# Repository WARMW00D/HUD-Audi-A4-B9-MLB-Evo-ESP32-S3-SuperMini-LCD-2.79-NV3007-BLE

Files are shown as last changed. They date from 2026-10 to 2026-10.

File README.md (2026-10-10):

# HUD for Audi A4 B9 (MLB-Evo) — ESP32-S3 Super Mini / NV3007 2.79″ / BLE

[Русская версия](README_ru.md) · [Android companion app](https://github.com/WARMW00D/HUD-Audi-A4-B9-MLB-Evo-Android-App)

A DIY head-up display showing vehicle data from Audi I-CAN: speed, gear, ACC, speed limiter, driver assistance, traffic signs, doors and navigation. This is the compact **428 × 142 NV3007** adaptation of the [Waveshare 3.49″ project](https://github.com/WARMW00D/HUD-Audi-A4-B9-MLB-Evo-Waveshare-ESP32-S3-Touch-LCD-3.49), with Android settings and firmware updates over BLE.

**Verified vehicle configuration:** operation was checked on an **Audi A4 B9 facelift (restyling) with MIB3 High infotainment**.

**Firmware: v29.1.9. Android app: 1.4.1.** This repository contains firmware source and wiring diagrams. Android source lives in its own repository. Prebuilt v29.1.9 app firmware and Android 1.4.1 APKs are available in Releases below.

## Tank capacity, acceleration bar and overspeed tolerance

Source versions: **HUD firmware v29.1.9 / Android app 1.4.1 (versionCode 5)**.

- **Tank capacity:** enter a whole number from **1 to 200 litres**; default **54 L**. The capacity is always entered in litres, even with US gallons selected, and updates the HUD fuel-to-add calculation.
- **Acceleration bar:** turn it on or off from the app. When enabled, the existing bar uses valid acceleration/speed data; it remains empty while stationary or without valid data.
- **Overspeed tolerance:** set **0–100 km/h**, default **20 km/h**, always entered in km/h even with mph selected. The red speed outline fades in from 75% of tolerance and is fully red at 100%; zero makes any positive overspeed fully red.
- All three settings are confirmed by BLE readback and saved in HUD NVS. Existing settings, phone owner and gateway bonds are retained. A BOOT phone-binding reset also retains these settings.

These controls need **app 1.4.1 + firmware v29.1.9**. App 1.4.1 still supports older firmware: missing controls are disabled. Maintainer-supplied APK 1.4.1 and v29.1.9 app-BIN are published in Releases; integrity was verified. If v29.0 and its OTA partition table are already installed, v29.1 uses the same layout; earlier firmware needs the initial USB/partition upgrade described below.

## HUD on hardware

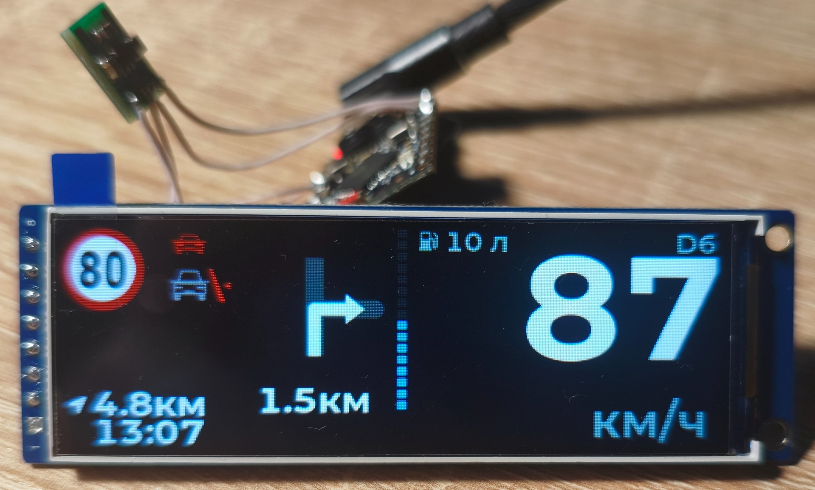
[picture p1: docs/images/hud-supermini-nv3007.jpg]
ESP32-S3 SuperMini HUD on the NV3007 2.79-inch display


Photo supplied by WARMW00D: speed, gear, speed-limit sign, navigation and fuel information on the NV3007 display.

## Download firmware BIN

[v29.1 release](https://github.com/WARMW00D/HUD-Audi-A4-B9-MLB-Evo-ESP32-S3-SuperMini-LCD-2.79-NV3007-BLE/releases/tag/v29.1.9) · [App-BIN](https://github.com/WARMW00D/HUD-Audi-A4-B9-MLB-Evo-ESP32-S3-SuperMini-LCD-2.79-NV3007-BLE/releases/download/v29.1.9/HUD-SuperMini-v29.1.9-app.bin) · [SHA-256](https://github.com/WARMW00D/HUD-Audi-A4-B9-MLB-Evo-ESP32-S3-SuperMini-LCD-2.79-NV3007-BLE/releases/download/v29.1.9/SHA256SUMS-v29.1.9.txt).

Maintainer-supplied image, **1,149,616 bytes**. ESP32-S3 header, image checksum and SHA-256 were verified. **OTA application only**: no bootloader or partition table. Initial installation requires USB with the project `partitions.csv`; this app-BIN cannot migrate partitions. The v29.0 two-slot OTA layout is compatible. Real-device OTA transfer has not been verified here.

## Download Android APK

[Version 1.3](https://github.com/WARMW00D/HUD-Audi-A4-B9-MLB-Evo-Android-App/releases/tag/v1.4.1) — **Pre-release**, pending real-device OTA validation.

- [Release APK](https://github.com/WARMW00D/HUD-Audi-A4-B9-MLB-Evo-Android-App/releases/download/v1.4.1/HUD-Control-1.4.1-release.apk) — normal installation, 58.4 KB.
- [Debug APK](https://github.com/WARMW00D/HUD-Audi-A4-B9-MLB-Evo-Android-App/releases/download/v1.4.1/HUD-Control-1.4.1-debug.apk) — 66.5 KB; `testOnly=true`: `adb install -r -t HUD-Control-1.4.1-debug.apk`.
- [SHA-256](https://github.com/WARMW00D/HUD-Audi-A4-B9-MLB-Evo-Android-App/releases/download/v1.4.1/SHA256SUMS-v29.1.9.txt).

WARMW00D supplied these builds: version 1.3 (versionCode 4). APK v2 signatures and content digests were verified. Each flavor retains its previous signing key: release updates release and debug updates debug. Switching flavors requires uninstalling the app and loses its local settings.

## What the HUD shows

| Element | Behaviour |
|---|---|
| Speed and gearbox | Cluster digital speed; P/R/N/D/S/M/E/Offroad and gear number when available |
| ACC and limiter | Set speed, ACC target and traffic jam assist; LIM replaces the ACC set-speed icon |
| Lane / Side Assist | Lane detection, steering and warnings; red lines for blind-spot indications |
| Traffic signs | Main sign: valid VZE → explicit PSD → PSD legal limit; additional signs cycle |
| Overspeed | Red outline around speed digits, based on the displayed main limit |
| Navigation | Main maneuver, next maneuver, distance, progress bar, destination distance and time |
| Doors / pre sense | Open vehicle parts replace navigation; pre sense has higher priority |
| Turn signals | Green arrows; hazard lights use red |
| Fuel | Amount to fill and consumption strip when the required data is available |
| Acceleration | Optional bar, selected by build-time configuration |
| Brightness | Vehicle light sensor × dimmer wheel; night range **2–40**, sunlight **200–255** |
| Settings | PSD, VZE, HUD language, distance/speed units and fuel-volume units; stored in NVS |

Stale fields are hidden. A signal must exist on your car’s bus to be displayed. This board has no Waveshare touch controller, audio codec or SD logging; settings use the phone. The phone app language is independent of the HUD language.

## Architecture

The HUD decodes raw frames locally using `can_decode.c`. Select the source in `supermini_hud/hud_config.h`:

| Mode | Source |
|---|---|
| `HUD_SRC_AUTO` — default | Own CAN while frames arrive; after 1 s of silence, use the BLE gateway |
| `HUD_SRC_TWAI` | Direct CAN through TJA1051T/3, TWAI `LISTEN_ONLY` |
| `HUD_SRC_BLE` | Raw CAN frames from a compatible gateway / sniffer |
| `HUD_SRC_FAKE` | Built-in generator for bench testing |

The [CAN sniffer / BLE gateway](https://github.com/WARMW00D/esp32-CAN-sniffer-logger-screener) uses the ACL protocol (firmware 2.6.0+). The HUD sends its ACL after every gateway connection. Phone settings and OTA are separate GATT services; NimBLE acts as both gateway client and phone server. First-time gateway pairing waits if the phone is connected.

LVGL renders a compact 518 × 172 canvas, uniformly scales it to 428 × 142, and sends changed strips over SPI. Display code uses PSRAM; no LVGL calls should be added from BLE callbacks.

[CAN signals and gateway protocol](docs/CAN.md) · [BLE settings, Russian](supermini_hud/BLE_SETTINGS_ru.md)

## Hardware and wiring

- **ESP32-S3 Super Mini:** the project targets the supplied 4 MB Flash / 2 MB QSPI PSRAM board. Check your board variant.
- **NV3007 2.79″:** 428 × 142, SPI, with a logic backlight-control input.
- **TJA1051T/3:** VIO-equipped CAN module with a 3.3 V logic interface.
- ACC 12 V → external DC-DC 12→5 V. The 5 V rail supplies the ESP32 board and the **input** of a separate DC-DC 5→3.3 V for the display.

**Display VDD comes from the separate converter’s 3.3 V output (`3V3_D`). Do not connect that output to the board’s 3V3 pin (`3V3_P`).** All grounds are common. CAN-module VCC comes from the board’s 5V pin; VIO and S come from the board’s 3V3 pin. SN65HVD230 is not used.

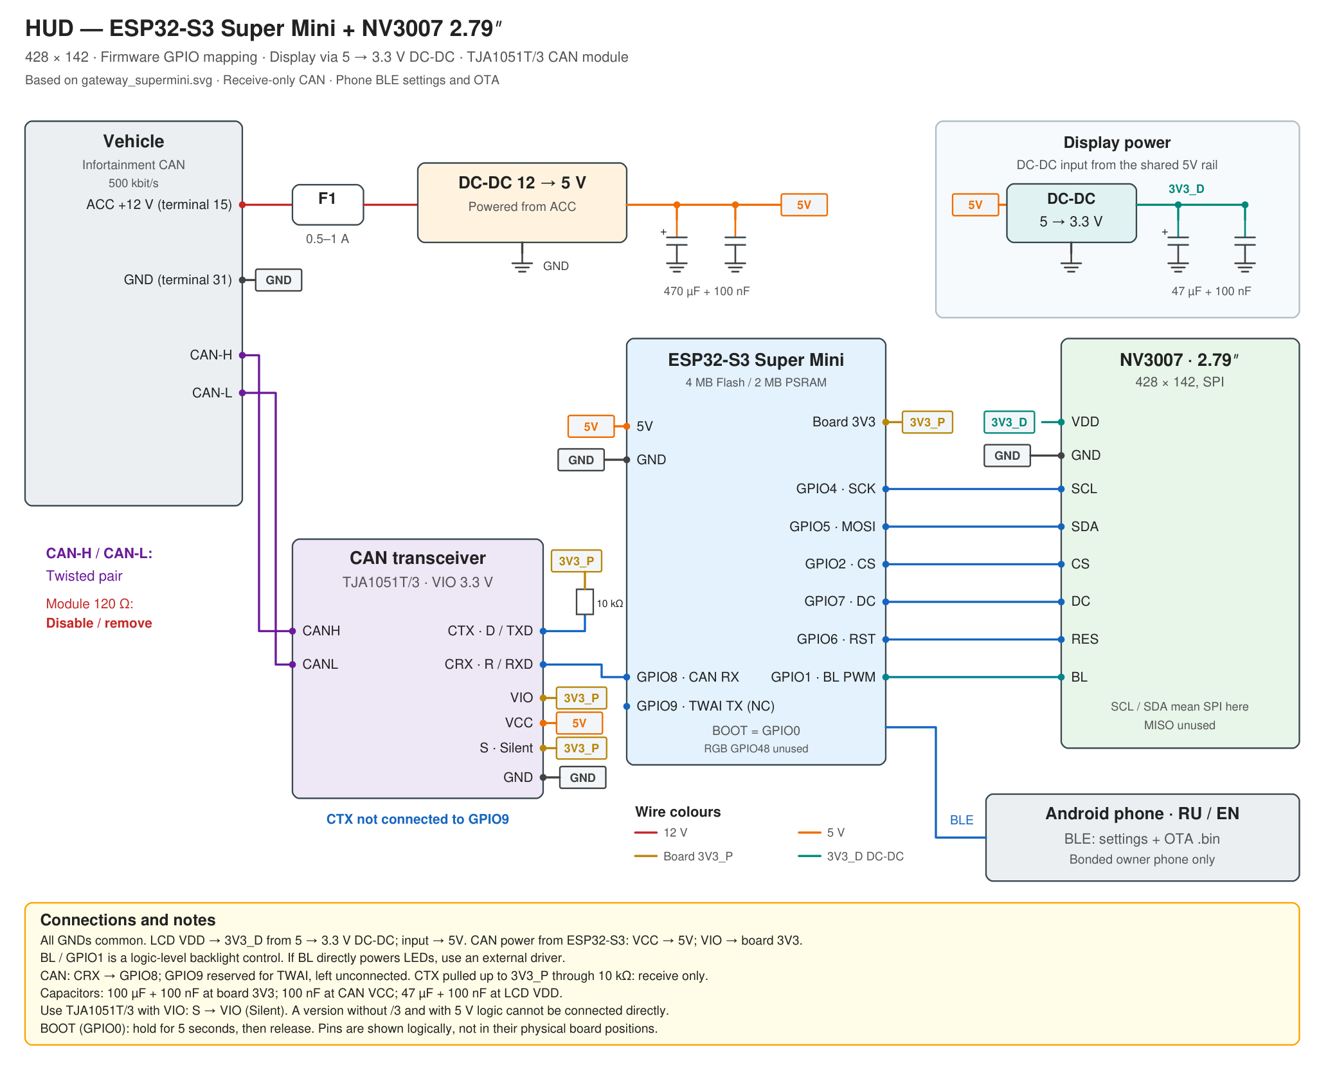
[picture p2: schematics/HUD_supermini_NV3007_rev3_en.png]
HUD wiring, revision 3


[Editable SVG](schematics/HUD_supermini_NV3007_rev3_en.svg) · [PDF](schematics/HUD_supermini_NV3007_rev3_en.pdf)

| ESP32-S3 | Connection |
|---|---|
| GPIO4 | LCD SCL / SPI SCK |
| GPIO5 | LCD SDA / SPI MOSI |
| GPIO2 | LCD CS |
| GPIO7 | LCD DC |
| GPIO6 | LCD RES |
| GPIO1 | LCD BL / PWM |
| GPIO8 | CAN CRX / RXD |
| GPIO9 | TWAI TX reservation — leave physically unconnected |
| GPIO0 | On-board BOOT button |

CAN CTX/TXD → 10 kΩ → board 3V3; S → VIO for silent mode. CAN-H / CAN-L are a twisted pair. Disable the module’s 120 Ω termination when connecting to an already terminated vehicle bus. Receive-only protection combines TWAI `LISTEN_ONLY`, disconnected GPIO9 and hardware silent mode. SCL/SDA labels on this display refer to SPI, not I²C; MISO is unused. If BL directly powers LEDs instead of being a logic input, use a suitable external driver.

The drawing is a wiring diagram, not a PCB layout or a complete automotive power-protection design. USB power isolation is not drawn; account for it when flashing while external 5 V is connected.

## 3D-printed enclosure

The [`case/`](case/) folder contains an ASA enclosure for the NV3007 2.79″ display: a top shell with a visor and a bottom plate secured with screws from below.

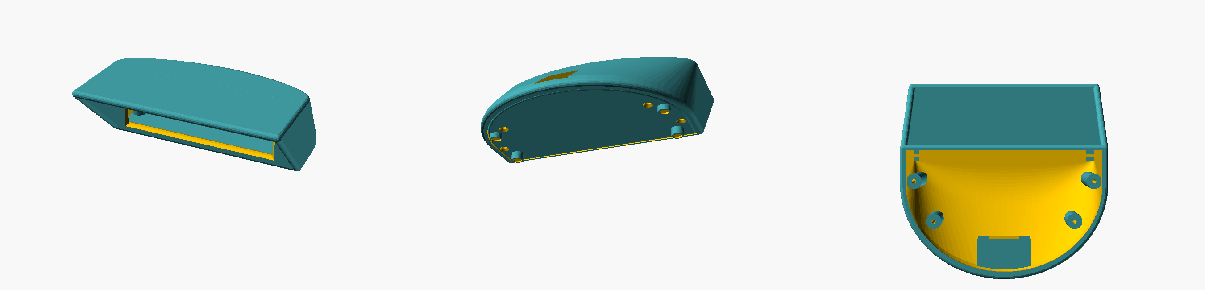
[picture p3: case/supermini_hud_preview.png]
SuperMini HUD enclosure preview


| Part | STL for printing | STEP for CAD |
|---|---|---|
| Top shell with visor | [STL](case/supermini_hud_shell.stl) | [STEP](case/supermini_hud_shell.step) |
| Top shell with long visor, variant 2 | [STL](case/supermini_hud_shell_var2.stl) | [STEP](case/supermini_hud_shell_var2.step) |
| Bottom plate with feet | [STL](case/supermini_hud_plate.stl) | [STEP](case/supermini_hud_plate.step) |
| Bottom plate without feet | [STL](case/supermini_hud_plate_nofeet.stl) | [STEP](case/supermini_hud_plate_nofeet.step) |
| Separate feet | [STL](case/supermini_hud_feet.stl) | [STEP](case/supermini_hud_feet.step) |

[Parametric OpenSCAD source](case/supermini_hud.scad). Dimensions are in millimetres. Use `PART` to select `assembly`, `shell`, `plate`, `plate_nofeet` or `feet`. The model is designed for **ASA**.

## Build and first USB installation

Open `supermini_hud/supermini_hud.ino` in Arduino IDE. Keep the sketch-folder name `supermini_hud`.

| Item | Project configuration |
|---|---|
| Board | ESP32S3 Dev Module |
| Arduino ESP32 core | 3.3.10, as in the supplied working board configuration |
| CPU | 240 MHz |
| Flash | 4 MB, QIO / 80 MHz, matching your working board |
| PSRAM | QSPI, 2 MB; not OPI |
| USB CDC On Boot | Enabled |
| Partition table | Custom `supermini_hud/partitions.csv` |
| Serial | 115200 |
| Libraries | LVGL 8.4.0; NimBLE-Arduino 2.x / API 2.5.1; Arduino_GFX with `Arduino_NV3007` support |

Put `supermini_hud/config/lv_conf.h` next to the installed `lvgl/` directory. Required: `LV_COLOR_DEPTH 16`, `LV_USE_FONT_COMPRESSED 1`. LVGL 9 is not supported. Both `LV_COLOR_16_SWAP` settings are handled by the display port.

**Upgrading v28.x → v29.0 requires USB flashing of the new partition table. Set Erase All Flash to Disabled.** Confirm the build uses the supplied CSV and writes the table at 0x8000; flashing only the application does not migrate partitions. NVS remains at 0x9000 with size 0x5000, so settings and bonds are intended to survive, subject to device verification.

Two OTA slots are **0x1F0000 / 2,031,616 bytes** each. Check the compiled application size. The first boot should report `[fw] HUD Super Mini v29.1.9 / BLE OTA` and a next-slot capacity of 2031616.

For gateway authentication, copy `secrets.example.h` to `secrets.h` and set its `BLE_PASSKEY` to match the gateway. `secrets.h` is ignored by Git. This is separate from the phone PIN, `HUD_SETTINGS_PIN` in `user_config.h`.

### Optional photoresistor light sensor

The SuperMini can use an optional photoresistor divider on **GPIO10 (ADC1)** when RLS_01 light data is unavailable. Connect the LDR from 3V3 to GPIO10, a 10 kΩ resistor from GPIO10 to GND, and optionally 100 nF from GPIO10 to GND. Calibration is available in the Android app: close the sensor and save the dark point once, then illuminate it with a bright flashlight and save the bright point once.

Photoresistor divider

## Android settings and BLE OTA

1. Download the APK above or build and install the [Android app](https://github.com/WARMW00D/HUD-Audi-A4-B9-MLB-Evo-Android-App).
2. Find `HUD-SuperMini`, connect and complete Android bonding. Phone pairing PIN: see `HUD_SETTINGS_PIN` in [`user_config.h`](supermini_hud/user_config.h).
3. The first authenticated phone becomes the owner. Settings changes are read back and stored in NVS.
4. For OTA, export **`supermini_hud.ino.bin`** from Arduino IDE. Select that application image in the app, then confirm the update.
5. Keep power stable and the phone app open. After verification and boot-slot selection, the HUD reboots; reconnect and check operation.

Do not use bootloader, partition, merged images or flash dumps for OTA. The transfer validates offsets, SHA-256, the ESP32-S3 application header and the ESP-IDF image before selecting the new slot. Only the bonded, authenticated owner may update. A lost final acknowledgment can mean the update has already committed; follow the app’s restart/check message before retrying. Functional rollback of a faulty new program is not guaranteed; USB is the recovery method.

To replace the phone: while the HUD is running, hold **BOOT for 5 s and release**. Only the phone ownership/bonds are reset; HUD settings and gateway keys remain. Remove the old HUD bond on the phone before pairing again. Do not hold BOOT during power-on/reset.

[Full OTA guide](docs/OTA.md) · [Полная инструкция OTA](docs/OTA_ru.md)

## Configuration and diagnostics

`user_config.h` defines LCD GPIO, orientation, column offsets, SPI clock, phone name/PIN and BOOT. `hud_config.h` defines data source, sign selection defaults, units, tank size, brightness and Serial logging. Stored phone settings override initial defaults.

| Setting | Default |
|---|---|
| `HUD_CAN_RX_PIN` / `HUD_CAN_TX_PIN` | 8 / 9, with TX unconnected |
| `HUD_CAN_BITRATE_K` | 500 |
| `HUD_LCD_SPI_HZ` / `HUD_LCD_ROTATION` | 20 MHz / 1 |
| `HUD_BR_DARK_WHEEL_MIN` / `_MAX` | 2 / 40 |
| `HUD_BR_BRIGHT_WHEEL_MIN` / `_MAX` | 200 / 255 |
| `HUD_LANG` / `HUD_UNITS` | RU / km |
| `HUD_TANK_L` | 54 L |

For bench testing, use `HUD_SRC_FAKE` or a compatible BLE log player. Enable `HUD_LOG_CAN` / `HUD_LOG_STAT` to diagnose missing frames; a field disappearing on timeout does not necessarily indicate a rendering problem. Use `tools/can_bitdiff.py` to inspect changing CAN bits.

| Symptom | Check |
|---|---|
| Custom text missing | `LV_USE_FONT_COMPRESSED 1` and LVGL 8 |
| Black screen / allocation error | QSPI PSRAM enabled, GPIO, power, LCD rotation and column offsets |
| No gateway data | Gateway ACL protocol, name, bonding/passkey and source mode |
| OTA service absent | Install v29.0 over USB; reconnect after Service Changed; check slot capacity |
| App reconnect fails after removing Android bond | Reset phone ownership with BOOT, then pair again |

## Validation status

WARMW00D supplied the v29.1.9 ESP32-S3 application BIN and Android v1.4.1 APKs. Firmware image checksum/SHA-256 and APK signatures/content digests were verified. Host tests pass. Builds were not run here; Android lint and real-device OTA transfer testing remain pending.

Host tests cover real SHA-256 through OpenSSL with mocked NimBLE/ESP-IDF: full transfer, commit only after verification, invalid size/header/chip/hash, flash failures, offsets, cancel/disconnect/timeout, owner authorization, duplicate commit and lost final ACK. Display scaling, dirty strips, decoder and settings/NVS also have host tests. Mocks do not establish real BLE interoperability or flash reliability.

Example from `supermini_hud/` (g++ and OpenSSL development headers required):

```sh
g++ -std=c++17 -Wno-deprecated-declarations -Itests/settings_stubs tests/test_ble_ota.cpp -lcrypto -o /tmp/hud_test_ota
/tmp/hud_test_ota
g++ -std=c++17 -Wno-deprecated-declarations -Itests/settings_stubs tests/test_ble_settings.cpp -lcrypto -o /tmp/hud_test_settings
/tmp/hud_test_settings
```

CAN signal verification depends on the vehicle and equipment. The inherited observations and remaining uncertainties are in [CAN reference](docs/CAN.md). Firmware integrity checks are not a digital signature or proof that a third-party ESP32-S3 image is compatible.

## Files

- `case/` — enclosure models (STL/STEP), parametric OpenSCAD source and preview.
- `supermini_hud/` — Arduino sketch, decoder, LVGL interface, SPI port, BLE gateway client, phone settings and OTA server.
- `supermini_hud/config/` — LVGL configuration example.
- `supermini_hud/tests/` — host tests and stubs.
- `supermini_hud/tools/` — image/font generators, previews and CAN utilities.
- `docs/` — OTA and CAN/gateway guides in English and Russian.
- `schematics/` — Russian and English revision 3 SVG, PNG and PDF with the Infortainment CAN label; display DC-DC input is 5 V. Revision 2 remains available.

## Credits and license

- **WARMW00D (Warmwood):** project owner, hardware integration, vehicle logs and testing.
- **Claude (Anthropic):** development assistance acknowledged by the original Waveshare project.
- **OpenAI Codex / ChatGPT:** assistance with the SuperMini/NV3007 adaptation, BLE settings, Android RU/EN app, BLE OTA, host tests, wiring diagrams and documentation. Generated changes still require maintainer review and hardware validation.
- [CAN sniffer/gateway](https://github.com/WARMW00D/esp32-CAN-sniffer-logger-screener), opendbc/openpilot and revag-bap — data transport and signal/protocol references.
- Waveshare — original project context; Arduino_GFX, LVGL and NimBLE-Arduino — display and BLE libraries.
- Montserrat and Roboto Condensed — fonts under SIL OFL 1.1, licenses in `supermini_hud/tools/fonts/`.

Project code and documentation: [MIT](LICENSE), retaining the original Warmwood copyright. Third-party assets retain their own licenses; the original README notes that `tools/icons/acc_set.png` came from an external source. This hobby project is not affiliated with AUDI AG or Volkswagen AG.

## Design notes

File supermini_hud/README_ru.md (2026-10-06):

# HUD Super Mini / NV3007 — вариант v29.0

Исходная версия: приложенный waveshare_hud_v27_1.zip.
Плата: ESP32-S3 Super Mini, 4 MB Flash / 2 MB QSPI PSRAM.
Дисплей: NV3007 2.79", 142×428 в портретной ориентации, 428×142 в альбомной.

## OTA v29.0

BLE OTA через Android HUD Control 1.2. Первую установку выполнить через USB
вместе с новым partitions.csv, без полного стирания. См. **../docs/OTA_ru.md**.

## Изменения

- Удалены тач и экранное меню настроек. Язык, единицы и PSD/VZE меняются
  по BLE и сохраняются в NVS вместе с владельцем; hud_config.h задаёт значения
  по умолчанию. Остальные графические параметры задаются константами.
- Удалены звук, PCM-файлы, кодек ES8311, I²S и расширитель GPIO TCA9554.
  Side Assist сохраняет визуальные предупреждения, звуков нет.
- Удалены SD-драйвер и файловое логирование, задача записи и буфер журнала.
  Убраны подписка BLE на Diagnose_01 0x6B2 и декодер часов, использовавшийся
  только для имён файлов и временных меток SD-журнала. Диагностика в Serial остаётся.
  Navigation_SD в названиях BAP — имя автомобильного сервиса навигации,
  к физической SD-карте HUD оно отношения не имеет и сохранено.
- QSPI-дисплей AXS15231B заменён на обычный SPI NV3007 через Arduino_GFX.
  Плата Waveshare, SensorLib и её драйверы больше не нужны.
- Сохранены CAN-декодирование остальных сигналов, BLE ACL, TWAI LISTEN_ONLY,
  AUTO/BLE/TWAI/FAKE, автояркость, ассистенты, двери, PSD/VZE, маршрут и расход.

## Раскладка на весь экран

Сначала ширина зоны навигации уменьшена **192 → 128** (ровно в 1.5 раза).
Основные стрелки пересозданы с пропорциональным уменьшением **192×116 → 128×77**;
они центрированы по высоте над прежней строкой дистанции.
Малые стрелки: 38×23 → 25×15. Машинка и PreSense центрированы в узкой зоне.
Свободные горизонтальные промежутки между блоками сокращены; поля выравнивания
скорости и передачи укорочены без изменения размера шрифта. Три цифры скорости
помещаются в поле 244 пикселя (табличный шаг цифры около 81.2 пикселя).
Бар дистанции сделан тоньше, сегменты бара ускорения уплотнены под новую ширину.

Итоговая логическая раскладка **518×172** масштабируется на весь **428×142**:
коэффициент по X 0.82625, по Y 0.82558. Разница менее 0.1%, вызвана округлением
до целых пикселей. Дополнительных чёрных полей и обрезки кадра нет.
Используется билинейное масштабирование RGB565, чтобы сгладить мелкий текст.

Один кадр LVGL занимает **178192 байта PSRAM**; выходной блок 428×8 —
**6848 байт внутренней RAM**. Буфер предыдущего изображения для сравнения полос
занимает ещё **121552 байта PSRAM**; отдельного буфера поворота нет.
Остальная память расходуется LVGL, BLE и исходной логикой. Общий расход памяти,
скорость обновления и размер прошивки требуется измерить после сборки на плате.

## Подключение дисплея

Пины выбраны для этой версии, существующую проводку при необходимости изменить
в user_config.h. Номера GPIO не равны порядковым номерам контактов платы.
На модуле подписи SCL/SDA обозначают **SPI SCK/MOSI**, это не I²C.

| Контакт дисплея | Super Mini | Параметр |
|---|---|---|
| GND | GND | общая земля |
| VDD | 3V3_D выхода DC-DC 5 → 3,3 В | согласно приложенному описанию, VDD допускает 3–5 V |
| SCL | GPIO4 | HUD_LCD_SCK |
| SDA | GPIO5 | HUD_LCD_MOSI |
| RES | GPIO6 | HUD_LCD_RST |
| DC | GPIO7 | HUD_LCD_DC |
| CS | GPIO2 | HUD_LCD_CS |
| BL | управление от GPIO1 | EXAMPLE_PIN_NUM_BK_LIGHT |

Сигналы управления — 3.3 V. MISO не используется.
**BL:** в описании указан ток светодиодов 100 mA, но полная схема модуля
не приложена. GPIO1 можно подключать напрямую только к логическому входу
установленного на модуле драйвера подсветки. Если BL питает светодиоды напрямую,
нужен внешний транзисторный/токовый драйвер; 100 mA через GPIO не подавать.
По умолчанию яркость активна высоким уровнем. Для инверсного входа/драйвера
поставить HUD_BL_ACTIVE_HIGH 0. Частота PWM — 5 kHz.

SPI по умолчанию 20 MHz. При нестабильном изображении снизить HUD_LCD_SPI_HZ
до 10000000. HUD_LCD_ROTATION 1 — альбомная ориентация, 3 — переворот на 180°.
HUD_LCD_COL_OFFSET_1/2 = 12/14 соответствует конфигурации NV3007 142×428
в официальном примере Arduino_GFX. HUD_LCD_INVERT можно переключить 0/1,
если конкретному модулю требуется инверсия панели.

## Источник данных

Сохранён исходный HUD_DATA_SOURCE = HUD_SRC_AUTO. Если собственного CAN-трансивера
нет, предпочтительно выбрать **HUD_SRC_BLE** в hud_config.h.
Для проверки без машины: **HUD_SRC_FAKE**. Имя шлюза: S3-CAN-Sniffer.
BLE-шлюз/сниффер должен поддерживать исходный ACL-протокол (прошивка 2.6.0+).
Если включена защита, скопировать secrets.example.h в secrets.h и вписать
тот же BLE_PASSKEY, что у шлюза.

Для схемы с TJA1051T/3: VCC → 5V платы, VIO и S → 3V3 платы,
GND общая. CRX/RXD → GPIO8. CTX/TXD подтянуть 10 кΩ к VIO.
GPIO9 оставить неподключённым (TWAI LISTEN_ONLY). Терминацию 120 Ω на модуле
отключить при подключении к уже терминированной шине автомобиля.
VDD дисплея питается от отдельного DC-DC 5 → 3,3 В; вход преобразователя —
от общей линии 5V. Выход DC-DC не соединять с контактом 3V3 ESP32-S3.

## Сборка Arduino IDE

Открыть **supermini_hud/supermini_hud.ino**. Имя папки и скетча должно совпадать.

| Настройка | Значение |
|---|---|
| Плата | ESP32S3 Dev Module |
| ESP32 Arduino core | 3.3.10 — версия из приложенного отчёта платы |
| CPU | 240 MHz |
| Flash Size | 4 MB |
| Flash Mode / Frequency | QIO / 80 MHz, как в рабочей конфигурации вашей платы |
| PSRAM | QSPI PSRAM, 2 MB; не OPI |
| USB CDC On Boot | Enabled |
| Partition Scheme | файл partitions.csv в папке скетча |

В partitions.csv теперь **два OTA-приложения app0/app1 по 0x1F0000**
(1984 KiB), otadata, NVS и coredump. Файловой системы нет. В выводе сборки
проверить применение файла из папки скетча. Максимум app .bin: 2031616 байт.
Для перехода с v28.x нужно впервые загрузить новую таблицу через USB.

Библиотеки:

- **lvgl 8.4.0**. LVGL 9 не подходит.
- **NimBLE-Arduino 2.x**; исходный BLE-код рассчитан на API 2.5.1.
- **GFX Library for Arduino** (Arduino_GFX), актуальная версия с Arduino_NV3007
  и поддержкой ESP32 Arduino core 3.3.10. Сам архив эту библиотеку не содержит.

Скопировать **config/lv_conf.h** рядом с каталогом установленной библиотеки lvgl:
Documents/Arduino/libraries/lv_conf.h и Documents/Arduino/libraries/lvgl/.
Критично: LV_COLOR_DEPTH 16 и LV_USE_FONT_COMPRESSED 1.
**LV_COLOR_16_SWAP может быть 0 или 1**: драйвер автоматически учитывает
активную настройку LVGL до масштабирования и передаёт Arduino_GFX обычный RGB565.
Буфер LVGL при этом не изменяется. Можно оставить общий lv_conf.h с
LV_COLOR_16_SWAP 1 для Waveshare и собирать оба проекта без переключения этой
настройки. Если общий lv_conf.h уже работает на Waveshare, заменять его файлом
config/lv_conf.h не требуется; этот файл — пример для новой установки.

Serial: 115200. При отключённой/неверно выбранной PSRAM прошивка выдаёт
диагностическое сообщение и останавливается. Успешное начало SPI не доказывает,
что экран физически подключён правильно: обратного чтения дисплея нет.

## Проверки и ограничения

В этом окружении **нет Arduino/ESP32 toolchain**, поэтому полноценная сборка
для ESP32, прошивка платы и проверка конкретного NV3007 не выполнены.
Готовый бинарник не прилагается. Перед использованием требуется сборка в IDE
и проверка на вашей плате, включая ориентацию, цвета и управление подсветкой.

Выполнены локальные проверки:

- C-модуль масштабирования с UndefinedBehaviorSanitizer: сохранение чистых
  RGB565-цветов, совпадение при масштабе 1:1, источник 1×1, все 142 выходные строки;
  одинаковый результат для обоих порядков байтов и неизменность входного буфера.
- CAN-декодер с подставными часами и блокировками: скорость, её таймаут,
  отсутствие обновления удалённых часов и сохранение позиций битов valid.
- Проверка локальных заголовков и отсутствия ссылок на удалённые подсистемы.

Тесты в tests/ предназначены для обычного компьютера с C-компилятором,
они не заменяют компиляцию и аппаратную проверку ESP32. Запуск из папки скетча:

```sh
cc -std=c11 -Wall -Wextra -Werror -fsanitize=undefined -I src/display tests/test_scale.c src/display/hud_scale.c -o /tmp/hud_test_scale
/tmp/hud_test_scale
cc -std=c11 -Wall -Wextra -fsanitize=undefined -I tests/stubs -I . tests/test_decode.c can_decode.c psd_speedlimit.c -o /tmp/hud_test_decode
/tmp/hud_test_decode
```

Исходники Arduino_GFX и пример подключения:
https://github.com/moononournation/Arduino_GFX
https://github.com/moononournation/Arduino_GFX/blob/master/examples/PDQgraphicstest/Arduino_GFX_display.h

## Исправление v27.3 и проверка чёрного экрана

В `lvgl_port.cpp` теперь явно передана последовательность
`nv3007_279_init_operations` из Arduino_GFX для дисплея **2.79″**.
Предыдущий вызов конструктора соответствовал примеру для 1.65/1.68″.
Источник: https://github.com/moononournation/Arduino_GFX/blob/master/examples/PDQgraphicstest/Arduino_GFX_display.h

Распиновка сохранена из присланного проекта: SCK=4, MOSI=5, CS=2, DC=7,
RST=6, BL=1, CAN RX=8, CAN TX=9 (не подключать).
Поддержка LV_COLOR_16_SWAP=0 и 1 сохранена.

Если HUD всё ещё не показывает изображение, открой отдельно
`tools/nv3007_test/nv3007_test.ino` в Arduino IDE и загрузи на ту же плату.
Нужна только GFX Library for Arduino с `nv3007_279_init_operations`;
LVGL, PSRAM, CAN и BLE в этом тесте не используются.
Тест использует SPI 10 MHz и показывает красный, зелёный, синий и белый
цвета по кругу. BL предполагается активным высоким уровнем, как в проекте.
Если тест работает, а HUD нет — пришли лог основного скетча после Reset
(115200 бод), проверь QSPI PSRAM. Если тест тоже чёрный — пришли его лог
и фото подключения. Успешный begin() означает запуск SPI и отправку команд,
а не подтверждение ответа дисплея (MISO отсутствует).

Сборка ESP32 и проверка на физическом дисплее здесь не выполнены.

## Изменения v27.4

Полоска расхода топлива отключена (`HUD_FUEL_BAR=0`); объект полоски
не создаётся. Значок бензоколонки и подпись количества топлива для долива
сдвинуты вместе вправо на 10 пикселей итогового экрана: 12 пикселей
виртуального холста 518 px при масштабировании в 428 px.
Инициализация NV3007 2.79″ и распиновка сохранены из работающей v27.3.

## Изменения v27.5

Скорость с обводкой, режим КП, единицы скорости, ACC, лимитер и значок
режима пробки сдвинуты вправо на ширину убранной полоски расхода:
5 пикселей холста, приблизительно 4 пикселя физического экрана.
Значок бензоколонки и количество для долива остались на позиции v27.4.
Правый поворотник сдвинут до края на 2 пикселя холста: дальше его
46-пиксельный контейнер выходил бы за экран.

## Изменения v27.6 — уменьшение объёма вывода по SPI

После масштабирования каждая полоса изображения сравнивается с предыдущим
кадром. Неизменившиеся полосы не передаются; в изменившейся полосе
передаётся только прямоугольник изменённых пикселей. Удаление старых цифр
также учитывается. Первый кадр передаётся целиком.

Дополнительный буфер предыдущего кадра занимает 121552 байта PSRAM
(около 119 КиБ), помимо холста LVGL 178192 байта. Внутренняя память
под блок 428×8 остаётся прежней. Частота SPI сохранена: 20 MHz.
Макет v27.5, распиновка и инициализация 2.79″ сохранены.

LVGL по-прежнему рисует полный виртуальный холст, а масштабирование
обрабатывает весь кадр. Оптимизация уменьшает передачу по SPI; она
не ускоряет приход CAN/BLE-данных и не гарантирует устранение разрыва
кадра при сканировании матрицы. Измерение частоты кадров на ESP32 не выполнено.

Проверки на компьютере: восстановление изображения из изменённых
прямоугольников точно совпадает с исходным кадром, включая стирание,
крайние пиксели, последнюю неполную полосу и 100 случайных изменений.
Проверка выполнена с UndefinedBehaviorSanitizer.

## Исправление v27.7

В v27.5/v27.6 настройка HUD_FUEL_BAR оказалась включена снова.
Теперь из интерфейса полностью удалены объект полоски, его создание,
обновление и переключение среднего/моментального режима, а также
соответствующие настройки. Значок бензоколонки и количество для долива
сохранены. Оптимизация вывода v27.6 и положение правой зоны сохранены.

## Изменения v27.8

Правая зона сдвинута ещё на 5 пикселей холста (примерно 4 пикселя
физического экрана), суммарный сдвиг теперь 10 пикселей холста.
Значок бензоколонки и количество для долива оставлены на позиции v27.4.
Правый поворотник уже у края экрана, его положение сохранено.
У цифр скорости справа 5 пустых пикселей; с учётом красной обводки
видимые пиксели остаются в пределах холста 518 px.

## Изменения v27.9

Ширина каждого голубого сегмента вертикальной полоски расстояния
увеличена с 4 до 8 пикселей холста, то есть вдвое. Левый край, высота,
промежутки, 16 сегментов и логика заполнения сохранены.

## v28.0 — управление настройками по BLE

Добавлены переключатели PSD/VZE, RU/EN, км/мили, литры/галлоны США,
сохранение настроек и владельца в NVS, PIN по умолчанию **482731**
(`HUD_SETTINGS_PIN` в user_config.h) и привязка к одному телефону.
После привязки — адресная BLE-реклама для владельца. BOOT GPIO0 удерживать
5 секунд и отпустить: сбрасывается только телефон, настройки остаются.
GPIO1 остаётся подсветкой. Приоритет основного знака теперь VZE → PSD.
Подробная инструкция и UUID: **BLE_SETTINGS_ru.md**.

## Исправление v28.1 — повторное подключение Android

Адресная реклама заменена подключаемой анонимной рекламой без имени
и UUID, с фильтром владельца. Проверка identity address перенесена
с onConnect на завершение аутентификации, когда доступна разрешённая
идентичность телефона. Добавлены диагностические сообщения соединения.
NVS, PIN, настройки, разметка Flash и привязка из v28.0 сохраняются.
Не использовать Erase All Flash при загрузке, если нужно сохранить NVS.

## v28.2 — ночная яркость NV3007

`HUD_BR_DARK_WHEEL_MIN = 2`, `HUD_BR_DARK_WHEEL_MAX = 40` в `hud_config.h`.
BLE, NVS, распиновка и графика сохранены из приложенной рабочей v28.1.
Сборка ESP32 и проверка новой яркости на плате не выполнялись.

## v29.0 — BLE OTA

Новый OTA-сервис доступен только привязанному аутентифицированному телефону.
Передача с контролем смещений, SHA-256 и валидацией ESP-IDF, отдельный COMMIT.
При незавершённой передаче текущий раздел остаётся загрузочным.
Полная инструкция: ../docs/OTA_ru.md; схема: ../schematics/.

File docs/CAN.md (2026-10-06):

# CAN and gateway reference

Adapted from the Waveshare project README. Verification labels below are the original project’s observations, not new SuperMini hardware tests. Decoder source in `../supermini_hud/` is authoritative.

## Data sources (CAN)

All signals are Intel (little-endian). Extraction:

```c
static inline uint32_t sig(const uint8_t *d, int start, int len) {
    uint64_t raw = 0; for (int i = 7; i >= 0; i--) raw = (raw << 8) | d[i];
    return (raw >> start) & ((1ULL << len) - 1);
}
```

### Regular frames (11-bit)

| What | ID | Message | Signal | start\|len | Scale / values | Verified |
|---|---|---|---|---|---|---|
| Speed | 0x30B | Kombi_01 | KBI_V_Digital | 24\|9 | ×1 km/h | ✅ |
| ACC set speed | 0x2A6 | ACC_12 | ACC_Wunschgeschw_02 | 12\|10 | ×0.32 km/h, 1023 = none | ✅ |
| Limit from ACC | 0x2A6 | ACC_12 | ACC_Tempolimit | 0\|5 | table in `vze_table.h` | ⚠️ |
| Lead target | 0x2A6 | ACC_12 | ACC_Relevantes_Objekt_02 | 45\|2 | 0 none, 1 vehicle, 2 warning, 3 passive | ⚠️ |
| ACC distance | 0x2A6 | ACC_12 | ACC_Gesetzte_Zeitluecke | 37\|3 | 1…5 (decoded, not drawn) | ⚠️ |
| Lane centering | 0x2A6 | ACC_12 | ACA_Querfuehrung | 7\|2 | 2 = active | ⚠️ |
| Traffic jam assist | 0x2A6 | ACC_12 | STA_Primaeranz | 62\|2 | 1 ready, 2 active, 3 warning | ⚠️ |
| ACC status | 0x2A8 | ACC_14 | ACC_Status_Anzeige | 16\|3 | 2 standby, 3 active, 4 driver override | ✅ |
| Speed limiter | 0x31E | — (not in K-matrix) | set speed | 12\|10 | ×0.32 km/h, **1022 off**, 1023 on without speed | ✅ parked |
| Gear mode | 0x394 | WBA_03 | WBA_Fahrstufe_02 | 12\|4 | 1 P, 2 R, 3 N, 4 D, 5 S, 6 M, 8 E, 12 Offroad | ✅ |
| Gear number | 0x394 | WBA_03 | WBA_eing_Gang_02 | 24\|4 | 1…9 | ✅ D1…, ⚠️ 8th |
| Turn signals | 0x366 | Blinkmodi_02 | left / right phase, hazard | 27, 28, 20 | bit | ✅ |
| Sign | 0x181 | VZE_01 | VZE_Verkehrszeichen_1 | 11\|8 | code; limit = 5 × code (8 → 40, 12 → 60, 16 → 80) | ✅ three points |
| Sign: suppress / overspeed | 0x181 | VZE_01 | Anzeigeunterdrueck_1 / Warnung_1 | 50 / 35 | bit | ⚠️ |
| Lane Assist | 0x397 | LDW_02 | green / yellow LED | 62 / 61 | bit | ⚠️ |
| LKA lines | 0x397 | LDW_02 | Lernmodus_links / _rechts | 38\|2 / 36\|2 | 0 off, 1 not seen, 2 seen, 3 departure | ✅ 0→1 when switched on |
| LKA warning | 0x397 | LDW_02 | Warnung_links / _rechts | 56 / 57 | bit | ⚠️ |
| Doors, boot | 0x583 | ZV_02 | ZV_FT/BT/HFS/HBFS/HD_offen | 24…28 | bit | ✅ |
| Bonnet | 0x65A | BCM_01 | BCM1_MH_Schalter | 31 | bit | ✅ |
| Acceleration | 0x101 | ESP_02 | ESP_Laengsbeschl | 24\|10 | ×0.03125 − 16 m/s² | ⚠️ opendbc MLB, check presence on I-CAN |
| Acceleration (fallback) | 0x30B | Kombi_01 | KBI_angez_Geschw (derivative) | 48\|10 | ×0.32 km/h | ✅ layout |
| Brakes | 0x106 | ESP_05 | ESP_Bremsdruck / ESP_Fahrer_bremst | 16\|10 / 26 | ×0.3 − 30 bar / bit | ⚠️ opendbc MLB |
| PSD: segments | 0x462 | PSD_04 | Segment_ID / Vorgaenger / Segmentlaenge / Strassenkategorie / Bebauung | 0\|6 / 6\|6 / 12\|7 / 19\|3 / 43 | length ×2 m | ✅ drives 29.09 |
| PSD: position | 0x463 | PSD_05 | Pos_Segment_ID / Pos_Segmentlaenge (remaining) | 0\|6 / 6\|7 | ×2 m | ✅ |
| PSD: limits | 0x464 | PSD_06 mux 2 | Ges_Segment_ID / Offset / Geschwindigkeit / Typ / Ueberholverbot / Gesetzlich_Kategorie | 3\|6 / 9\|7 / 16\|5 / 21\|2 / 49\|2 / 56\|3 | code → km/h (lower bound), 23 = end | ✅ |
| Trip computer | 0x17330F10 (29-bit) | BAP_BC, LSG 0x0F, from the cluster | fct 0x18 "since start" / 0x19 long-term: [0–1] consumption ×0.1 L/100 (0xFFFF none), [6–7] distance ×0.1 km, [11] time, min, [15–16] avg speed ×0.1; 0x16 range, km; 0x17 odometer ×0.1 km; 0x1C fuel, % | LE | ✅ drives 0006/0010 |
| Side Assist | 0x30F | SWA_01 | SWA_Infostufe_SWA_li / _re, SWA_Warnung_SWA_li / _re | 26 / 42, 27 / 43 | bit: car in blind spot / warning | ⚠️ opendbc MLB, check on I-CAN |
| Dimmer wheel | 0x64F | BCM1_04 | BCM1_Stellgroesse_Kl_58s | 25\|7 | 1–100 % | ✅ log 0003 |
| Light sensor | 0x5A0 | RLS_01 | LS_Helligkeit_FW / LS_Helligkeit_IR / RLS_Vorfeldhelligkeit_Boost / RS_Regenmenge | 8\|10 / 0\|8 / 35\|4 / 24\|4 | ×6 lx (≤1021) / ×400 lx / 0–15 / ×10 % | ✅ drives 0006/0010 |
| Date and time | 0x6B2 | Diagnose_01 | UH_Jahr / Monat / Tag / Stunde / Minute / Sekunde | 28\|7 / 35\|4 / 39\|5 / 44\|5 / 49\|6 / 55\|6 | year +2000 | ⚠️ opendbc; frame present on I-CAN |
| Fuel | 0x107 | Motor_04 | MO_KVS (counter, µL) | 48\|15 | wraps at 32768 | ⚠️ opendbc MLB |
| Pre sense | 0x2A9 | ACC_15 | AWV_Warnung | 16\|3 | 0 none, 1 latent, 2 warning, 3 acute, 4 braking, 5 take over, 6 turning | ⚠️ from opendbc MQB |
| Brightness | 0x5F0 | Dimmung_01 | DI_KL_58xd / DI_Display_Nachtdesign | 0\|8 / 15 | final display brightness 10–100 % (254 Init, 255 error) / night design | ✅ log 0003, dimmer wheel |

`LDW_02`: **do not use** bits 12–15 (`LDW_Gong`, `LDW_SW_Warnung_*`) — on this car byte 1
is always `0x40`. When LKA is switched on while parked, LEDs 61/62 do not change but the
lines go to 1 — so "LKA on" = any line non-zero.

### Navigation: BAP Navigation_SD (29-bit)

IDs `0x17333210` and `0x17333211` (MIB → displays). BAP framing:

- `b0.bit7 = 0` — single frame: header `b0<<8 | b1`, data from byte 2;
- `b0 = 10cc LLLL` — start of a multi-frame message: length `(b0&0xF)<<8 | b1`, header in b2..b3;
- `b0 = 11cc SSSS` — continuation, channel `cc`, sequence `SSSS`.

Header: `opcode = hdr>>12 & 7` (3 = HeartbeatStatus, 4 = Status), `lsg = hdr>>6 & 0x3F`
(must be `0x32`), `fct = hdr & 0x3F`.

| fct | Function | Used for |
|---|---|---|
| 0x11 | RG_Status | 1 = route guidance active (main switch for showing navigation) |
| 0x12 | DistanceToNextManeuver | distance ×10 (LE), unit, bar graph % |
| 0x15 | DistanceToDestination | distance to destination |
| 0x16 | TimeToDestination | type (travel time / arrival), hours, minutes |
| 0x17 | ManeuverDescriptor | up to 3 maneuvers in a row: MainElement, Direction, Z-level, side-street count + their directions. The first (main arrow) and second (next) are used |

`Direction`: 0x00 straight, 0x40 left, 0x80 back, 0xC0 right (360/256 deg, counter-clockwise).

### Freshness timeouts

| Field | Timeout | Why |
|---|---|---|
| Speed, ACC, gear mode, gear number, limiter, jam assist | 1 s | frames arrive 5–10 times/s after the ACL |
| Sign, Lane Assist, doors | 1.5 s | intervals of 500–1000 ms |
| Turn signals | 2.5 s | `Blinkmodi_02` is sent once per second when idle |
| Bonnet | 3 s | `BCM_01` is sent once per second |
| Navigation | 60 s | BAP sends Status only on change, heartbeat ~25 s |

---

## Sniffer → HUD BLE protocol

The full protocol description on the sniffer/gateway side is in [esp32-CAN-sniffer-logger-screener](https://github.com/WARMW00D/esp32-CAN-sniffer-logger-screener). Below is what the HUD needs.

Service `A1B2C3D4-0001-41A2-9E3B-000000000001`, device `S3-CAN-Sniffer`.

| UUID | Properties | Purpose |
|---|---|---|
| `…0007` | WRITE, READ | ACL rule list |
| `…0008` | NOTIFY | stream of frames that passed the ACL |

Sequence: connect with MTU 247 → subscribe to `…0008` → write the ACL to `…0007` → the HUD
reads it back and compares (Serial prints "ACL прочитан обратно — совпадает").

**ACL format:** `[0x01][12-byte rule] × N`. Rule: `flags` (bit0 PERMIT, bit1 EXT,
bit2 ONCHANGE, bit3 ANYFMT), `reserved`, `minIntervalMs` (2 bytes), `id` (4), `mask` (4).
The first matching rule wins, with an implicit `deny any` at the end.

**Stream format:** `[count][flags: bit0 loss][frame]×count`, frame =
`ts(2) idf(4: bit31 EXT, bit30 RTR) dlc(1) data(dlc)`.

### HUD rule list (20 rules, 241 bytes)

| ID | Interval | Purpose |
|---|---|---|
| 0x30B | 100 ms | speed |
| 0x2A6, 0x2A8 | 200 ms | ACC, traffic jam assist |
| 0x31E | 200 ms | limiter (has CRC and counter) |
| 0x2A9 | 100 ms | pre sense |
| 0x5F0 | 100 ms | brightness (the wheel sends frames every ~60 ms) |
| 0x5A0 | 200 ms | light sensor |
| 0x64F | 100 ms | dimmer wheel |
| 0x30F | 100 ms | Side Assist (CRC — no ONCHANGE) |
| 0x462/0x463 (mask `0x7FE`), 0x464 | — | PSD: a stream of multiplexes, rate filters would lose records |
| 0x394 | 200 ms | gear mode and gear number |
| 0x366 | — | turn signals: every phase change is needed |
| 0x181 | 500 ms | signs |
| 0x397 | 500 ms | Lane Assist |
| 0x583 | 1000 ms | doors, boot |
| 0x65A | — | bonnet (already once per second) |
| 0x17330F10 (EXT) | — | BAP_BC: cluster trip computer, multi-frame |
| 0x17333210/11 (EXT, mask `0x1FFFFFFE`) | — | BAP navigation: multi-frame, rate limiting would break it |

**Why intervals instead of `ONCHANGE`.** With `ONCHANGE` an unchanged value is never sent
again: if the speed or an open door stays the same longer than the timeout, the field
disappears, and after a reconnect the HUD does not know the current state. Also, frames
with a CRC and counter (0x31E, 0x394) change every time, so `ONCHANGE` filters nothing.

---

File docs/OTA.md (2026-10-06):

# BLE OTA — HUD v29.0 / Android app 1.2

[Русская версия](OTA_ru.md)

## Initial migration: USB required

v28.x uses one factory application partition. OTA cannot replace the partition table. Install **v29.0 with the supplied `supermini_hud/partitions.csv` over USB** before using phone updates.

Open `supermini_hud/supermini_hud.ino`; keep your working board configuration (4 MB Flash, 2 MB QSPI PSRAM). Set **Erase All Flash = Disabled**. The initial USB upload must write the bootloader, new partition table and app. Check the build/upload output: it must use this sketch’s CSV and write the table at 0x8000. Flashing only an application `.bin` does not migrate the layout.

| Partition | Offset | Size |
|---|---:|---:|
| NVS | 0x9000 | 0x5000 / 20 KiB |
| otadata | 0xE000 | 0x2000 / 8 KiB |
| app0 | 0x10000 | 0x1F0000 / 1,984 KiB |
| app1 | 0x200000 | 0x1F0000 / 1,984 KiB |
| coredump | 0x3F0000 | 0x10000 / 64 KiB |

Maximum application image: **2,031,616 bytes**. Check the new firmware size after compilation. NVS offset and size are unchanged, so settings and bonding keys are intended to survive a non-erasing USB upload; verify this on the device. Do not reset phone ownership just to install OTA.

At Serial 115200, expect:

```text
[fw] HUD Super Mini v29.0 / BLE OTA
[ota] BLE service ready, next slot capacity=2031616
```

Capacity 0 indicates no usable OTA layout. The firmware sends Service Changed when the GATT schema is first upgraded; Android may ask you to reconnect. If the OTA service remains absent, toggle Android Bluetooth, restart the HUD and reconnect before considering a bond reset.

## Update the Android app

Build app 1.2 from [the Android repository](https://github.com/WARMW00D/HUD-Audi-A4-B9-MLB-Evo-Android-App). Install over the old app with the same application ID and signing key. Keep the existing Android project’s wrapper/local SDK configuration if replacing only `app/`. Use Gradle 8.9 / AGP 8.7.3 and an ASCII-only Windows path.

## Select the right image

Arduino IDE: Sketch → **Export Compiled Binary**. Choose **`supermini_hud.ino.bin`**, the application image built for this HUD. Do not select `*.bootloader.bin`, `*.partitions.bin`, `*.merged.bin` or a complete flash dump.

Future firmware must retain the compatible two-slot layout and OTA service. BLE OTA changes the application, not bootloader, partition table, eFuses or board hardware parameters. A valid ESP32-S3 header alone does not prove that an arbitrary firmware will work with this display or project.

## Transfer

1. Disconnect other BLE clients such as nRF Connect. Connect through HUD Control using the owner phone.
2. Open **Firmware update** and choose the application `.bin`.
3. The app checks the size/header and computes SHA-256.
4. Select **Update HUD**, check the filename and confirm.
5. Keep the app open, phone nearby and power stable. A transfer can take several minutes.
6. At 100%, wait: all bytes have arrived, but verification/commit may still be pending.
7. The HUD checks SHA-256 and validates the ESP-IDF image before choosing the boot slot.
8. After commit the HUD reboots. Reconnect and check graphics, settings and CAN data.

For the first test, you can transfer the same compiled v29.0 app into the other slot. Verify normal operation before relying on subsequent OTA updates.

## Cancellation, faults and recovery

Cancel is available before boot-slot commit. Cancel, disconnect, invalid hash/image or timeout before commit leaves the old boot slot selected. Resume is not implemented: start the next transfer from offset zero.

Firmware inactivity timeout: **120 s**. Android timeout per BLE operation: **30 s**. The HUD schedules reboot **2 s** after successful commit even if the final reply is lost.

If COMMIT acknowledgment is lost, the app reports an uncertain result: the slot may already have changed. Wait for reboot and check the HUD before retransmitting. Duplicate commit is idempotent; a late abort cannot undo a committed update.

| Error | Meaning |
|---:|---|
| 1 | Invalid command/packet |
| 2 | No suitable OTA partition layout |
| 3 | Size mismatch or image too large |
| 4 | Flash / SDK / boot selection failure |
| 5 | Wrong, skipped or repeated offset |
| 6 | SHA-256 mismatch |
| 7 | Invalid image, chip or ESP-IDF validation failure |
| 8 | Command in an invalid state |
| 9 | Session timeout |

Read/write access requires encrypted, authenticated bonding and saved owner identity. SHA-256 is an integrity check, **not a firmware signature**. Runtime rollback of a new application that passes image validation but malfunctions is not guaranteed by this implementation; USB remains the recovery path.

## Protocol v1

| Role | UUID |
|---|---|
| Service | `74d0a200-3d92-4f50-9b1a-478142000001` |
| Control READ / WRITE with response | `74d0a200-3d92-4f50-9b1a-478142000002` |
| Data WRITE with response | `74d0a200-3d92-4f50-9b1a-478142000003` |

No notifications. Integers are little-endian.

| Packet | Content |
|---|---|
| START | `01 + uint32(size) + SHA256[32]`, 37 bytes |
| Data | `uint32(offset) + 1…240 payload bytes`; first payload ≥36 bytes |
| END | `02`: verify complete image |
| COMMIT | `03`: choose next boot slot |
| ABORT | `04`: cancel an uncommitted session |

Control read returns 16 bytes: protocol version 1, state, error, reserved zero, then `uint32(received)`, `uint32(total)`, `uint32(capacity)`. States: Idle 0, Receiving 1, Verified 2, Committed 3, Error 4.

The app negotiates MTU (minimum 64), sends one operation at a time and checks the confirmed offset after each chunk. Ordinary settings are blocked in the app during OTA; changing the app language is allowed.

## Validation status

Host tests use real SHA-256 through OpenSSL and mocked NimBLE/ESP-IDF. They cover transfer, owner checks, commit-after-verification, lost final ACK/reboot, duplicate commit, header/chip/hash rejection, flash faults, offset/size failures, incomplete image, cancel/disconnect and timeout. Settings/NVS regression tests pass; mbedTLS 2/3 API branches were checked with host adapters.

**The ESP32/Android builds and real-device OTA transfer have not been performed in the authoring environment.** Real ESP-IDF image validation, GATT cache refresh, Flash behaviour and migration of bonds need device testing; host stubs do not verify those.

API references: [ESP-IDF OTA](https://docs.espressif.com/projects/esp-idf/en/stable/esp32s3/api-reference/system/ota.html), [NimBLE services](https://h2zero.github.io/NimBLE-Arduino/class_nim_b_l_e_service.html), [NimBLE server](https://h2zero.github.io/NimBLE-Arduino/class_nim_b_l_e_server.html), [Android BluetoothGatt](https://developer.android.com/reference/android/bluetooth/BluetoothGatt).

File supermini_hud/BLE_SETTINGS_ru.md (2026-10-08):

# Настройки HUD по BLE — v29.1

Открыть основной `supermini_hud.ino` из этого архива. Нужен NimBLE-Arduino
**2.5.1** (API 2.x). LVGL остаётся 8.4.0. Графика и GPIO дисплея не менялись.
Потребуются роли NimBLE central + peripheral, legacy advertising и минимум
два соединения для телефона и CAN-шлюза одновременно. Обычная конфигурация
NimBLE-Arduino поддерживает эти роли; нестандартные настройки библиотеки проверить.

## Первое подключение

1. Включить HUD. До привязки он доступен как **HUD-SuperMini**.
2. Открыть BLE-клиент на телефоне, например nRF Connect, найти HUD и подключиться.
3. В системном запросе сопряжения ввести PIN из `HUD_SETTINGS_PIN` в `user_config.h`. Если приложение предлагает
   Bond / сопряжение, выполнить его. Простого подключения без PIN недостаточно.
4. Открыть сервис `74d0a100-3d92-4f50-9b1a-478142000001`.
5. Для нужной характеристики выполнить Read или Write с ответом в формате Hex.
   Передавать ровно один байт: `00`/`01` для переключателей, `01`..`C8` для объёма бака (1..200 л). Это число, не текстовые символы.
6. После записи выполнить Read: прочитанное значение подтверждает сохранённую настройку.

| Настройка | UUID характеристики | `00` | `01` |
|---|---|---|---|
| PSD | `74d0a100-3d92-4f50-9b1a-478142000002` | выключить | включить |
| VZE | `74d0a100-3d92-4f50-9b1a-478142000003` | выключить | включить |
| Язык | `74d0a100-3d92-4f50-9b1a-478142000004` | RU | EN |
| Скорость и расстояние | `74d0a100-3d92-4f50-9b1a-478142000005` | км/ч, км, м | mph, mi, ft |
| Объём для долива | `74d0a100-3d92-4f50-9b1a-478142000006` | литры | галлоны США |
| Бар ускорения | `74d0a100-3d92-4f50-9b1a-478142000008` | выключить | включить |

Объём бака: `74d0a100-3d92-4f50-9b1a-478142000007`, один беззнаковый байт, 1..200 л. Например, 54 л = `36`, 63 л = `3F`, 200 л = `C8` (Hex). Единицы ввода всегда литры; настройка галлонов влияет только на отображение долива. Нулевой объём и многобайтовые записи отвергаются.

Толерантность: `74d0a100-3d92-4f50-9b1a-478142000009`, один байт `00`..`64` (0..100 км/ч); по умолчанию 20 (`14` Hex). Ноль — красная обводка при любом превышении; иначе прежнее плавное появление от 75% допуска. Единицы ввода — км/ч независимо от режима mph.

Фоторезистор: `...000A` — включение (`00`/`01`); `...000B` — команда записи точки «темно» (`01`); `...000C` — команда записи точки «ярко» (`01`). Перед записью первой точки полностью закройте сенсор, перед второй посветите на него ярким фонариком. Обе точки сохраняются в NVS как напряжение ADC.

Новые характеристики требуют приложения 1.3 и прошивки v29.1. В NVS используются отдельные ключи `tank-l`, `accel-bar`, `speed-tol`; запись прежних настроек/владельца остаётся совместимой. GATT schema marker = 4: после обновления переподключить телефон.

Настройки применяются при следующем обновлении интерфейса и сохраняются
автоматически в NVS через Preferences, в пространстве `hud-settings`.
Записываются только изменения. Некорректные значения игнорируются.
Если сохранение не удалось, настройка остаётся прежней; это видно при Read
и в Serial. Константы HUD_PSD_LIMITS, HUD_VZE_SIGNS, HUD_LANG, HUD_UNITS,
HUD_VOLUME_GAL, HUD_TANK_L, HUD_ACCEL_BAR и HUD_OVERSPEED_TOL_KMH задают начальные значения, когда в NVS ещё нет настроек.
После появления сохранённой записи изменение констант её не перезаписывает.

## PIN и безопасность

В `user_config.h`:

```cpp
// HUD_SETTINGS_PIN задаётся в user_config.h
#define HUD_SETTINGS_BLE_NAME "HUD-SuperMini"
#define HUD_SETTINGS_BOOT_PIN 0
#define HUD_SETTINGS_BOOT_HOLD_MS 5000
```

Это PIN **телефона**, независимый от `BLE_PASSKEY` CAN-шлюза в `secrets.h`.
Телефон должен завершить аутентифицированное зашифрованное сопряжение с bonding.
Первый успешно сопряжённый телефон становится единственным владельцем.
Его identity address и тип сохраняются в одной записи NVS с настройками;
ключи/IRK сохраняет NimBLE в своей NVS. Проверяется identity address,
а не временный случайный адрес телефона. Каждое чтение и запись требуют
принадлежности владельцу и аутентифицированного зашифрованного соединения.

После привязки используются обычные подключаемые BLE-пакеты без имени
и списка сервисов, с non-discoverable флагами и фильтром допустимого адреса
владельца. Адресная (directed) реклама из v28.0 заменена для совместимости
с Android. Посторонний BLE-сканер может видеть анонимные пакеты; полного
отсутствия в эфире скрытый режим не обеспечивает. Общая регистрация новых
телефонов закрыта, каждый доступ к настройкам требует сохранённых ключей
и identity address владельца. В onConnect адрес ещё может быть временным:
окончательная проверка выполняется после аутентификации/шифрования.

Повторное подключение делать из сохранённого/сопряжённого устройства
в приложении. Если искать сканированием, запись может отображаться
без имени: ориентироваться на сохранённый адрес HUD. Не удалять
сопряжение телефона и не сбрасывать BOOT при установке v28.1.
Прошивка не меняет формат NVS и сохраняет существующую привязку.
Если проблема сохраняется, нужен лог после подключения и перезапуска:
`Link connected`, `Owner authenticated`, `Auth rejected` или ошибка рекламы.

Если на телефоне удалить сопряжение, заново вводить PIN без сброса HUD нельзя:
сначала сбросить привязку кнопкой BOOT. Изменение PIN в константе не отзывает
уже сохранённые ключи: для нового PIN тоже сбросить привязку и удалить старое
сопряжение на телефоне.

## Сброс телефона

На работающем HUD удерживать **BOOT 5 секунд, затем отпустить**.
В Serial появится просьба отпустить BOOT; после отпускания HUD удалит
привязку и ключи только телефона, перезапустится и откроет общее сопряжение.
Выбранные настройки и ключи CAN-шлюза сохраняются. Чтобы повторно привязать
тот же телефон после сброса, удалить на нём прежнее сопряжение HUD.
Короткое нажатие ничего не меняет.

BOOT у ESP32-S3 — **GPIO0**, активный низкий уровень. GPIO1 остаётся подсветкой.
Не держать BOOT при включении питания или нажатии RESET: это вход в загрузчик.
Если BOOT конкретной платы подключён иначе, сверить схему платы и изменить
HUD_SETTINGS_BOOT_PIN. Источник:
https://docs.espressif.com/projects/esptool/en/latest/esp32s3/advanced-topics/boot-mode-selection.html

## Совместная работа с CAN-шлюзом и приоритет знаков

NimBLE инициализируется один раз; HUD одновременно предоставляет сервис
телефону и работает клиентом CAN-шлюза. При первом PIN-сопряжении шлюза
на короткое время закрывается подключение телефона: IO capability NimBLE
общая для обеих ролей. Если телефон уже подключён, первое сопряжение
нового шлюза откладывается до отключения телефона. Переподключение к уже
сопряжённому шлюзу может выполняться вместе с телефоном.

Раньше основной знак выбирался как явный PSD → VZE → PSD по правилам.
Теперь **действующий VZE имеет приоритет над PSD**. Если VZE выключен,
невалиден или подавлен, используется PSD (если он включён). При выключении
обоих источников основной знак скрывается. Дополнительные знаки VZE
по-прежнему могут показываться по очереди. PSD-запрет обгона не добавляется
поверх действующего основного VZE. Контроль превышения берёт основной знак.

## Что проверено

Проверки на компьютере: выбор основного знака на коде из hud_mockup.c;
модель callbacks BLE и NVS — владелец, отклонение чужого/незащищённого
соединения, пять настроек, неправильные значения, ошибка записи, восстановление
сохранённых значений, переход в анонимный режим с фильтром, тип identity address после
разрешения RPA, защита от одновременного PIN-сопряжения и BOOT 5 секунд.
Также прошли проверки масштабирования и частичного вывода изображения.

Модель использует заглушки библиотек; она не заменяет компиляцию настоящего
NimBLE/ESP32 SDK. Сборка ESP32, PIN-диалог телефона, повторное подключение,
работа с CAN-шлюзом и потребление памяти требуют проверки на вашей плате.

Модель BLE/NVS можно повторить на компьютере с g++:

```sh
g++ -std=c++17 -Wno-deprecated-declarations -Itests/settings_stubs tests/test_ble_settings.cpp -lcrypto -o test_ble_settings
./test_ble_settings
```

## Датчик освещённости

Опциональный фоторезистор подключается к GPIO10 (ADC1). В приложении включите датчик, затем нажмите «Сохранить темно» при полностью закрытом сенсоре и «Сохранить ярко» при освещении ярким фонариком. Прошивка сохраняет две точки в NVS и использует сенсор только при отсутствии свежих данных RLS_01.

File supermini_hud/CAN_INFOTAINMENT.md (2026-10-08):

# Infotainment I-CAN — краткая карта для HUD

Источник: `MLBevo_Gen2_MLBevo_ICAN_KMatrix_V8.21.01F_20210129_EICR.dbc`.
Шина: **I-CAN / Infotainment, 500 кбит/с**, Intel (little-endian) сигналы.

## Кадры, используемые HUD

| CAN ID | Имя в K-Matrix | Назначение в HUD |
|---:|---|---|
| `0x181` (385) | `VZE_01` | дорожные знаки 1–3, единицы, подавление, предупреждение о превышении |
| `0x29C` (668) | `VZE_02` | дорожные знаки 4–5; добавлен в локальный replay-декодер |
| `0x30F` (783) | `SWA_01` | Side Assist: `SWA_Infostufe_SWA_li/re` и `SWA_Warnung_SWA_li/re` |
| `0x397` (919) | `LDW_02` | Lane Assist; раскладка проверяется по логам, так как сообщения нет в приложенном DBC |

### VZE

В `VZE_01` знак 1 начинается с бита 11, знаки 2 и 3 — с битов 19 и 27. Флаги подавления — биты 50, 10 и 9. В `VZE_02` знаки 4 и 5 начинаются с битов 11 и 19; подавление — бит 63 для знака 4 и бит 8 для знака 5.

В проверенных replay-фрагментах `0x181` содержал `00 00 00 00 00 00 00 00`, поэтому активного VZE-знака в этих фрагментах не было. `0x29C` также не содержал ненулевых кодов знаков. Это позволяет отличить отсутствие знака на CAN от ошибки отрисовки HUD.

### Side Assist

Для `0x30F`:

- левая сторона: информация — бит 26, предупреждение — бит 27;
- правая сторона: информация — бит 42, предупреждение — бит 43.

В отрисовке Side Assist имеет приоритет над цветом линий Lane Assist: информационный/предупреждающий сегмент перекрашивается в красный и не заменяется жёлтым или зелёным LKA.

### Lane Assist и ACC

При одном только Lane Assist HUD рисует полосы, но не рисует собственную машину. Зелёный цвет собственной машины разрешён только при `ACC_Status_Anzeige = 3` (ACC реально регулирует); `4` отображается белым как ручное превышение заданной скорости. Для каждой полосы цвет берётся из собственного `LDW_Lernmodus`: видимая удерживаемая линия зелёная, нераспознанная жёлтая, вмешательство или выход за линию мигает оранжевым. Side Assist имеет приоритет.

## Источник данных на экране

В нижней части HUD показывается активный источник: `CAN` для собственного TWAI-трансивера, значок Bluetooth для BLE/гейта, а при отсутствии свежих данных — состояние отсутствия связи. В режиме `AUTO` CAN получает приоритет, пока от него недавно приходили кадры; после паузы снова используется BLE.

## Навигация и кольца

Навигация приходит отдельными BAP Navigation_SD сообщениями по 29-bit ID `0x17333210/0x17333211`. Для `MainElement = 0x15/0x16` HUD использует `Direction` и выбирает сектор изображения. Номер съезда отдельным полем в принятых кадрах не передаётся, поэтому спорные кольца остаются предметом дальнейшей проверки.

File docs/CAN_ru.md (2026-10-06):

# Справочник CAN и шлюза

Основано на README проекта Waveshare. Метки проверок ниже — наблюдения исходного проекта, а не новые испытания SuperMini. При расхождениях сверяться с кодом в `../supermini_hud/`.

## Источники данных (CAN)

Все сигналы — Intel (little-endian). Извлечение:

```c
static inline uint32_t sig(const uint8_t *d, int start, int len) {
    uint64_t raw = 0; for (int i = 7; i >= 0; i--) raw = (raw << 8) | d[i];
    return (raw >> start) & ((1ULL << len) - 1);
}
```

### Обычные кадры (11 бит)

| Что | ID | Сообщение | Сигнал | start\|len | Масштаб / значения | Проверено |
|---|---|---|---|---|---|---|
| Скорость | 0x30B | Kombi_01 | KBI_V_Digital | 24\|9 | ×1 км/ч | ✅ |
| ACC заданная | 0x2A6 | ACC_12 | ACC_Wunschgeschw_02 | 12\|10 | ×0.32 км/ч, 1023 = нет | ✅ |
| Лимит из ACC | 0x2A6 | ACC_12 | ACC_Tempolimit | 0\|5 | таблица в `vze_table.h` | ⚠️ |
| Цель впереди | 0x2A6 | ACC_12 | ACC_Relevantes_Objekt_02 | 45\|2 | 0 нет, 1 машина, 2 предупр., 3 пассив | ⚠️ |
| Дистанция ACC | 0x2A6 | ACC_12 | ACC_Gesetzte_Zeitluecke | 37\|3 | 1…5 (декодируется, не рисуется) | ⚠️ |
| Удержание в полосе | 0x2A6 | ACC_12 | ACA_Querfuehrung | 7\|2 | 2 = активно | ⚠️ |
| Режим пробки | 0x2A6 | ACC_12 | STA_Primaeranz | 62\|2 | 1 готов, 2 активен, 3 предупр. | ⚠️ |
| Статус ACC | 0x2A8 | ACC_14 | ACC_Status_Anzeige | 16\|3 | 2 пассив, 3 активен, 4 превышение водителем | ✅ |
| Лимитер | 0x31E | — (нет в K-матрице) | заданная скорость | 12\|10 | ×0.32 км/ч, **1022 выкл**, 1023 вкл без скорости | ✅ на стоянке |
| Режим КП | 0x394 | WBA_03 | WBA_Fahrstufe_02 | 12\|4 | 1 P, 2 R, 3 N, 4 D, 5 S, 6 M, 8 E, 12 Offroad | ✅ |
| Номер передачи | 0x394 | WBA_03 | WBA_eing_Gang_02 | 24\|4 | 1…9 | ✅ D1…, ⚠️ 8-я |
| Поворотники | 0x366 | Blinkmodi_02 | такт лев / прав, аварийка | 27, 28, 20 | бит | ✅ |
| Знак | 0x181 | VZE_01 | VZE_Verkehrszeichen_1 | 11\|8 | код; ограничение = 5 × код (8 → 40, 12 → 60, 16 → 80) | ✅ три точки |
| Знак: не показывать / превышение | 0x181 | VZE_01 | Anzeigeunterdrueck_1 / Warnung_1 | 50 / 35 | бит | ⚠️ |
| Lane Assist | 0x397 | LDW_02 | LED зелёный / жёлтый | 62 / 61 | бит | ⚠️ |
| Линии LKA | 0x397 | LDW_02 | Lernmodus_links / _rechts | 38\|2 / 36\|2 | 0 выкл, 1 не видна, 2 видна, 3 выход | ✅ 0→1 при включении |
| Предупреждение LKA | 0x397 | LDW_02 | Warnung_links / _rechts | 56 / 57 | бит | ⚠️ |
| Двери, багажник | 0x583 | ZV_02 | ZV_FT/BT/HFS/HBFS/HD_offen | 24…28 | бит | ✅ |
| Капот | 0x65A | BCM_01 | BCM1_MH_Schalter | 31 | бит | ✅ |
| Ускорение | 0x101 | ESP_02 | ESP_Laengsbeschl | 24\|10 | ×0.03125 − 16 м/с² | ⚠️ opendbc MLB, есть ли на I-CAN — проверить |
| Ускорение (запасное) | 0x30B | Kombi_01 | KBI_angez_Geschw (производная) | 48\|10 | ×0.32 км/ч | ✅ раскладка |
| Тормоза | 0x106 | ESP_05 | ESP_Bremsdruck / ESP_Fahrer_bremst | 16\|10 / 26 | ×0.3 − 30 бар / бит | ⚠️ opendbc MLB |
| PSD: сегменты | 0x462 | PSD_04 | Segment_ID / Vorgaenger / Segmentlaenge / Strassenkategorie / Bebauung | 0\|6 / 6\|6 / 12\|7 / 19\|3 / 43 | длина ×2 м | ✅ поездки 29.09 |
| PSD: позиция | 0x463 | PSD_05 | Pos_Segment_ID / Pos_Segmentlaenge (остаток) | 0\|6 / 6\|7 | ×2 м | ✅ |
| PSD: ограничения | 0x464 | PSD_06 mux 2 | Ges_Segment_ID / Offset / Geschwindigkeit / Typ / Ueberholverbot / Gesetzlich_Kategorie | 3\|6 / 9\|7 / 16\|5 / 21\|2 / 49\|2 / 56\|3 | код → км/ч (нижняя граница), 23 — конец | ✅ |
| Бортовой компьютер | 0x17330F10 (29 бит) | BAP_BC, LSG 0x0F, от приборки | fct 0x18 «с момента запуска» / 0x19 долговременная: [0–1] расход ×0.1 л/100 (0xFFFF — нет), [6–7] пробег ×0.1 км, [11] время, мин, [15–16] ср. скорость ×0.1; 0x16 запас хода, км; 0x17 одометр ×0.1 км; 0x1C топливо, % | LE | ✅ поездки 0006/0010 |
| Side Assist | 0x30F | SWA_01 | SWA_Infostufe_SWA_li / _re, SWA_Warnung_SWA_li / _re | 26 / 42, 27 / 43 | бит: машина в мёртвой зоне / предупреждение | ⚠️ opendbc MLB, на I-CAN проверить |
| Колёсико подсветки | 0x64F | BCM1_04 | BCM1_Stellgroesse_Kl_58s | 25\|7 | 1–100 % | ✅ лог 0003 |
| Датчик света | 0x5A0 | RLS_01 | LS_Helligkeit_FW / LS_Helligkeit_IR / RLS_Vorfeldhelligkeit_Boost / RS_Regenmenge | 8\|10 / 0\|8 / 35\|4 / 24\|4 | ×6 лк (≤1021) / ×400 лк / 0–15 / ×10 % | ✅ поездки 0006/0010 |
| Дата и время | 0x6B2 | Diagnose_01 | UH_Jahr / Monat / Tag / Stunde / Minute / Sekunde | 28\|7 / 35\|4 / 39\|5 / 44\|5 / 49\|6 / 55\|6 | год +2000 | ⚠️ opendbc; кадр есть на I-CAN |
| Расход | 0x107 | Motor_04 | MO_KVS (счётчик, мкл) | 48\|15 | переполнение на 32768 | ⚠️ opendbc MLB |
| Pre sense | 0x2A9 | ACC_15 | AWV_Warnung | 16\|3 | 0 нет, 1 латентное, 2 предупр., 3 острое, 4 торможение, 5 перехватите управление, 6 при повороте | ⚠️ из opendbc MQB |
| Яркость | 0x5F0 | Dimmung_01 | DI_KL_58xd / DI_Display_Nachtdesign | 0\|8 / 15 | итоговая яркость дисплеев 10–100 % (254 Init, 255 ошибка) / ночной дизайн | ✅ лог 0003, колёсико |

`LDW_02`: биты 12–15 (`LDW_Gong`, `LDW_SW_Warnung_*`) **не использовать** — на этой машине
байт 1 постоянно `0x40`. На стоянке при включении LKA индикаторы 61/62 не меняются, линии
переходят в 1 — поэтому «LKA включён» = любая линия не 0.

### Навигация: BAP Navigation_SD (29 бит)

ID `0x17333210` и `0x17333211` (MIB → дисплеи). Кадрирование BAP:

- `b0.bit7 = 0` — одиночный кадр: заголовок `b0<<8 | b1`, данные с байта 2;
- `b0 = 10cc LLLL` — старт многокадрового: длина `(b0&0xF)<<8 | b1`, заголовок в b2..b3;
- `b0 = 11cc SSSS` — продолжение, канал `cc`, номер `SSSS`.

Заголовок: `opcode = hdr>>12 & 7` (3 — HeartbeatStatus, 4 — Status), `lsg = hdr>>6 & 0x3F`
(должен быть `0x32`), `fct = hdr & 0x3F`.

| fct | Функция | Что берётся |
|---|---|---|
| 0x11 | RG_Status | 1 = маршрут ведётся (главный признак показа навигации) |
| 0x12 | DistanceToNextManeuver | дистанция ×10 (LE), единица, бар-граф % |
| 0x15 | DistanceToDestination | дистанция до цели |
| 0x16 | TimeToDestination | тип (в пути / прибытие), часы, минуты |
| 0x17 | ManeuverDescriptor | до 3 манёвров подряд: MainElement, Direction, Z-level, число боковых улиц + их направления. Берутся первый (основная стрелка) и второй (следующий) |

`Direction`: 0x00 прямо, 0x40 налево, 0x80 назад, 0xC0 направо (360/256 град, против часовой).

### Таймауты свежести

| Поле | Таймаут | Почему |
|---|---|---|
| Скорость, ACC, КП, № передачи, лимитер, режим пробки | 1 с | кадры идут 5–10 раз/с после ACL |
| Знак, Lane Assist, двери | 1.5 с | интервалы 500–1000 мс |
| Поворотники | 2.5 с | в покое `Blinkmodi_02` раз в секунду |
| Капот | 3 с | `BCM_01` раз в секунду |
| Навигация | 60 с | BAP шлёт Status только при изменении, heartbeat ~25 с |

---

## Протокол сниффер → HUD по BLE

Полное описание протокола со стороны сниффера и гейта — в [esp32-CAN-sniffer-logger-screener](https://github.com/WARMW00D/esp32-CAN-sniffer-logger-screener). Ниже — то, что нужно HUD.

Сервис `A1B2C3D4-0001-41A2-9E3B-000000000001`, устройство `S3-CAN-Sniffer`.

| UUID | Свойства | Назначение |
|---|---|---|
| `…0007` | WRITE, READ | список правил ACL |
| `…0008` | NOTIFY | поток кадров, прошедших ACL |

Порядок: подключение с MTU 247 → подписка на `…0008` → запись ACL в `…0007` → HUD читает
список обратно и сверяет (в Serial: «ACL прочитан обратно — совпадает»).

**Формат ACL:** `[0x01][правило 12 байт] × N`. Правило: `flags` (бит0 PERMIT, бит1 EXT,
бит2 ONCHANGE, бит3 ANYFMT), `reserved`, `minIntervalMs` (2 байта), `id` (4), `mask` (4).
Первое совпавшее правило решает, в конце неявный `deny any`.

**Формат потока:** `[count][flags: бит0 потери][кадр]×count`, кадр =
`ts(2) idf(4: бит31 EXT, бит30 RTR) dlc(1) data(dlc)`.

### Список правил HUD (20 правил, 241 байт)

| ID | Интервал | Зачем |
|---|---|---|
| 0x30B | 100 мс | скорость |
| 0x2A6, 0x2A8 | 200 мс | ACC, режим пробки |
| 0x31E | 200 мс | лимитер (есть CRC и счётчик) |
| 0x2A9 | 100 мс | pre sense |
| 0x5F0 | 100 мс | яркость (колёсико шлёт кадры каждые ~60 мс) |
| 0x5A0 | 200 мс | датчик света |
| 0x64F | 100 мс | колёсико подсветки |
| 0x30F | 100 мс | Side Assist (CRC — без ONCHANGE) |
| 0x462/0x463 (маска `0x7FE`), 0x464 | — | PSD: поток мультиплексов, фильтры по частоте потеряют записи |
| 0x394 | 200 мс | режим и номер передачи |
| 0x366 | — | поворотники: нужен каждый переход такта |
| 0x181 | 500 мс | знаки |
| 0x397 | 500 мс | Lane Assist |
| 0x583 | 1000 мс | двери, багажник |
| 0x65A | — | капот (кадр и так раз в секунду) |
| 0x17330F10 (EXT) | — | BAP_BC: бортовой компьютер приборки, многокадровый |
| 0x17333210/11 (EXT, маска `0x1FFFFFFE`) | — | BAP-навигация: многокадровая, фильтр по частоте её сломает |

**Почему интервалы, а не `ONCHANGE`.** С `ONCHANGE` неизменное значение не присылается
повторно: стоит скорости или открытой двери не меняться дольше таймаута — и поле гаснет,
а после переподключения HUD не знает текущего состояния. Кроме того, в кадрах с CRC и
счётчиком (0x31E, 0x394) данные меняются в каждом кадре, и `ONCHANGE` ничего не фильтрует.

---

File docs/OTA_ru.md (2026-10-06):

# OTA через BLE — HUD v29.0 / Android HUD Control 1.2

## Первая установка — только USB

Текущая v28.2 имеет один factory-раздел. OTA не может заменить таблицу разделов.
Первую установку **v29.0 с приложенным partitions.csv** выполнить через USB.
Открыть `supermini_hud/supermini_hud.ino` и оставить рабочие параметры платы
ESP32-S3 Super Mini, 4 MB Flash, 2 MB QSPI PSRAM и прежние библиотеки.

**Erase All Flash = Disabled.** Начальная USB-загрузка должна записать новый
bootloader, таблицу разделов и приложение; старое приложение занимает тот же
начальный адрес 0x10000. В журнале сборки/прошивки проверить, что выбрана
таблица из папки этого скетча и загружается новая таблица по адресу 0x8000.
Если IDE применяет встроенную схему вместо custom `partitions.csv`, остановить
миграцию и исправить выбор таблицы. Один `.bin` приложения новую таблицу не устанавливает.

| Раздел | Начало | Размер |
|---|---:|---:|
| NVS | 0x9000 | 0x5000 = 20 KiB |
| otadata | 0xE000 | 0x2000 = 8 KiB |
| app0 | 0x10000 | 0x1F0000 = 1 984 KiB |
| app1 | 0x200000 | 0x1F0000 = 1 984 KiB |
| coredump | 0x3F0000 | 0x10000 = 64 KiB |

Один OTA-файл: не более **2 031 616 байт**. Предыдущая прошивка 1 061 616 байт
помещалась с запасом, но размер новой v29.0 нужно проверить после сборки.
NVS остаётся по прежнему адресу и с прежним размером: настройки, владелец и
ключи сопряжения должны сохраниться при USB-прошивке без полного стирания.
BOOT-привязку ради OTA не сбрасывать.

После USB-загрузки Serial 115200 должен показать:

```text
[fw] HUD Super Mini v29.0 / BLE OTA
[ota] BLE service ready, next slot capacity=2031616
```

Если capacity=0 — OTA-разметка не установлена: проверить partitions.csv.
При первой версии с новым сервисом прошивка посылает Service Changed для
старого GATT-кэша Android. Приложение может попросить переподключиться.
Если OTA-сервис всё ещё не виден, сначала выключить/включить Bluetooth телефона,
перезапустить HUD и подключиться вновь. Сопряжение не удалять без необходимости.

## Обновить приложение

Обновить исходники отдельного [Android-приложения](https://github.com/WARMW00D/HUD-Audi-A4-B9-MLB-Evo-Android-App) и пересобрать APK. applicationId прежний,
версия приложения 1.2; устанавливать поверх существующего приложения с тем же
ключом подписи. Сохранённый адрес HUD и язык приложения должны остаться.
Gradle 8.9 / AGP 8.7.3. Использовать путь без кириллицы, например `D:\HUD\android`.
`prepare-and-build.ps1` собирает debug APK и запускает Android lint.

## Получить правильный .bin

Arduino IDE: Sketch / Скетч → **Export Compiled Binary / Экспорт бинарного файла**.
Для передачи выбрать **supermini_hud.ino.bin**, то есть отдельный образ приложения.
Не выбирать `*.bootloader.bin`, `*.partitions.bin`, `*.merged.bin` и полный
дамп Flash. Файл должен быть собран для этой платы и с OTA-совместимой разметкой.
Размер ограничен OTA-разделом даже если полная Flash имеет 4 MB.

Следующие версии исходников тоже должны сохранять два OTA-раздела и BLE OTA.
OTA не изменяет bootloader, partitions.csv, eFuse и аппаратные параметры платы.
Проверка заголовка подтверждает ESP32-S3 и тип образа приложения, но не доказывает,
что любая сторонняя ESP32-S3 прошивка совместима с этим HUD: выбирайте файл HUD.

## Передача с телефона

1. Отключить nRF Connect от HUD. Открыть HUD Control, подключиться обычным способом.
2. Внизу открыть раздел **«Обновление прошивки / Firmware update»**.
3. Нажать **«Выбрать .bin / Choose .bin»** и выбрать образ приложения.
4. Приложение проверит заголовок и размер, затем вычислит SHA-256.
5. Нажать **«Обновить HUD / Update HUD»**, проверить имя файла и подтвердить.
6. Держать приложение открытым, телефон рядом, питание HUD стабильным.
   Скорость зависит от Android и BLE; передача может занять несколько минут.
7. После передачи выполняются проверка SHA-256 и валидация образа ESP-IDF.
   100% на полоске означает передачу всех байтов, а не завершение проверки.
8. После отдельного подтверждения выбора загрузочного раздела HUD перезапустится.
   Подключиться заново, проверить графику, настройки и чтение CAN.

Для первой проверки можно передать тот же собранный v29.0 app `.bin` в соседний
OTA-раздел. Не проверять обрыв питания во время самого переключения otadata.

## Отмена и ошибки

Кнопка «Отменить передачу» доступна до команды переключения загрузочного
раздела. При отмене, обрыве до переключения, неправильном SHA-256 или неверном
образе новая прошивка не выбирается для следующей загрузки. Начать заново:
возобновление с промежуточного смещения в этой версии не реализовано.
Бездействие 120 секунд отменяет незавершённую сессию на HUD; Android ждёт ответ
на отдельную BLE-операцию не более 30 секунд.

Если подтверждение COMMIT потеряно, приложение **не объявляет обновление
неуспешным**: раздел мог уже переключиться. Оно просит дождаться перезагрузки
и проверить HUD перед повторной передачей. Перезапуск запланирован через две
секунды после успешного выбора boot-раздела, даже если телефон отключился.

| Код HUD | Причина |
|---:|---|
| 1 | Некорректный формат команды/пакета |
| 2 | Нет подходящей OTA-разметки |
| 3 | Размер не совпадает или не помещается |
| 4 | Ошибка Flash / SDK / выбора boot-раздела |
| 5 | Неверное смещение, пропуск или повтор блока |
| 6 | SHA-256 не совпал |
| 7 | Неверный образ, другой чип или ошибка проверки ESP-IDF |
| 8 | Команда в неверном состоянии |
| 9 | Таймаут сессии |

Все чтения/записи OTA требуют шифрованное, аутентифицированное сопряжение
и уже сохранённого владельца. Другой телефон не может начать передачу.
SHA-256 проверяет целостность; это не самостоятельная цифровая подпись прошивки.

Автоматический откат при **ошибке работы уже запущенной новой программы** здесь
не обещается: стандартный bootloader Arduino обычно не включает rollback.
Корректный бинарный формат не гарантирует отсутствие программных ошибок.
USB остаётся способом восстановления, если новая версия не запускается.

## Протокол v1

| Назначение | UUID |
|---|---|
| Сервис OTA | 74d0a200-3d92-4f50-9b1a-478142000001 |
| Control: READ / WRITE с ответом | 74d0a200-3d92-4f50-9b1a-478142000002 |
| Data: WRITE с ответом | 74d0a200-3d92-4f50-9b1a-478142000003 |

У всех характеристик требуется аутентификация. Notifications не используются.
Числа — little-endian. START: `01 + uint32(size) + SHA256[32]`, 37 байт.
Data: `uint32(offset) + 1…240 байт`. Первый блок содержит минимум 36 байт образа.
END `02` проверяет полный файл. COMMIT `03` выбирает его для загрузки.
ABORT `04` отменяет незавершённую сессию.

Control READ возвращает 16 байт: версия протокола (1), состояние, код ошибки,
нулевой резервный байт, uint32(received), uint32(total), uint32(capacity).
Состояния: 0 Idle, 1 Receiving, 2 Verified, 3 Committed, 4 Error.
Приложение согласует MTU (минимум 64), передаёт один блок за раз и читает
подтверждённое смещение после каждого блока. Изменение обычных настроек во время
OTA заблокировано в приложении. Язык самого приложения можно переключать.

## Что проверено здесь

Host-проверки C++ с настоящим SHA-256 (OpenSSL), имитацией NimBLE/ESP-IDF:
полная передача, переключение только после верификации, потеря финального ACK,
повтор COMMIT, плохой hash, неверный чип/образ, ошибки Flash, неправильное смещение,
переполнение/неполный файл, отмена, отключение, таймаут и отказ чужому телефону.
Регрессия BLE-настроек/NVS прошла. Ветки API mbedTLS 2/3 прошли на host-адаптере.
Также проверены таблица разделов, UUID и RU/EN ресурсы.

**Сборка ESP32 и APK, валидация реального ESP-IDF образа, Service Changed Android
и передача на вашей плате не проверены: соответствующих toolchain здесь нет.**
Host-моки не заменяют проверку реального BLE и Flash.

Источники API:
- https://docs.espressif.com/projects/esp-idf/en/stable/esp32s3/api-reference/system/ota.html
- https://h2zero.github.io/NimBLE-Arduino/class_nim_b_l_e_service.html
- https://h2zero.github.io/NimBLE-Arduino/class_nim_b_l_e_server.html
- https://developer.android.com/reference/android/bluetooth/BluetoothGatt

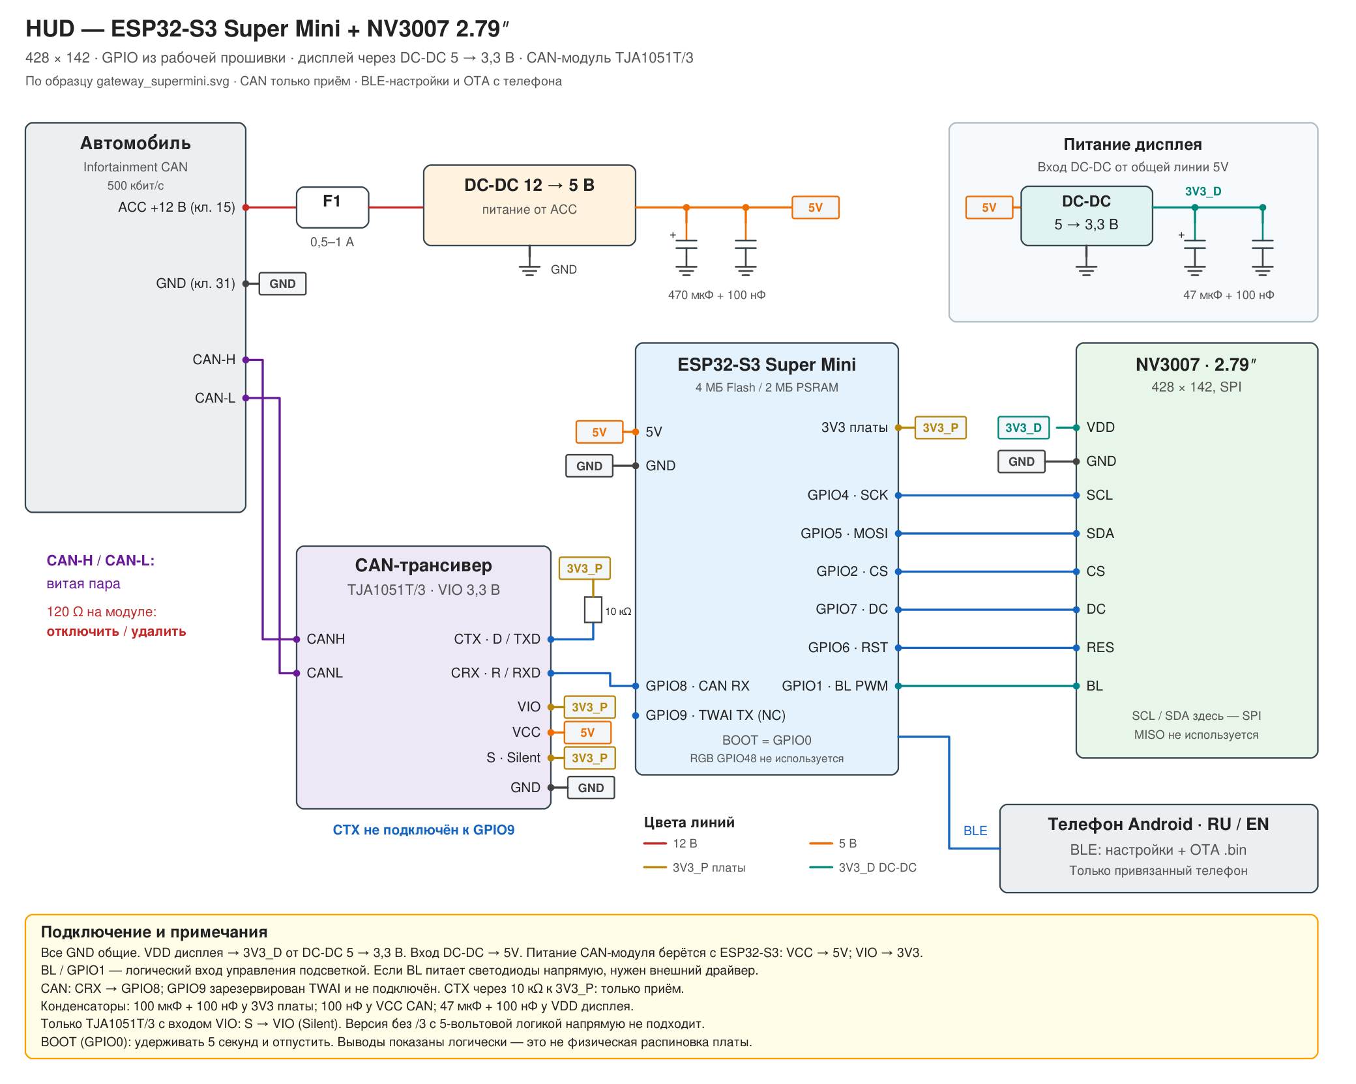
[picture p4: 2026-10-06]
schematics/HUD_supermini_NV3007_rev3_ru.png

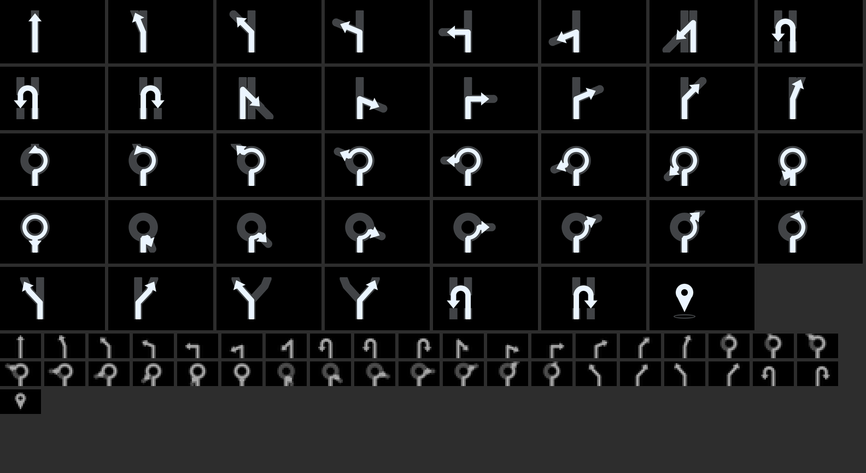
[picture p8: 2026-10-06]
supermini_hud/tools/preview_nav.png

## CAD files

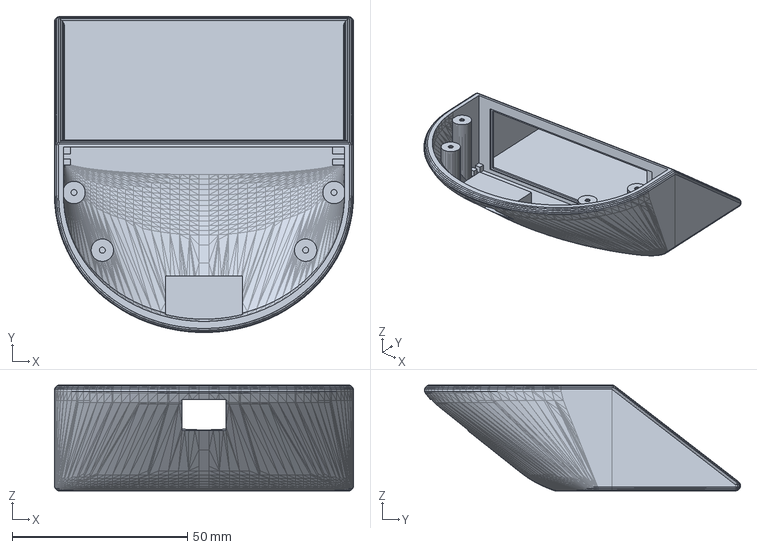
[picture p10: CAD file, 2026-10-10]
case/supermini_hud_shell_var2.step
85.3 x 90.2 x 30.2 mm

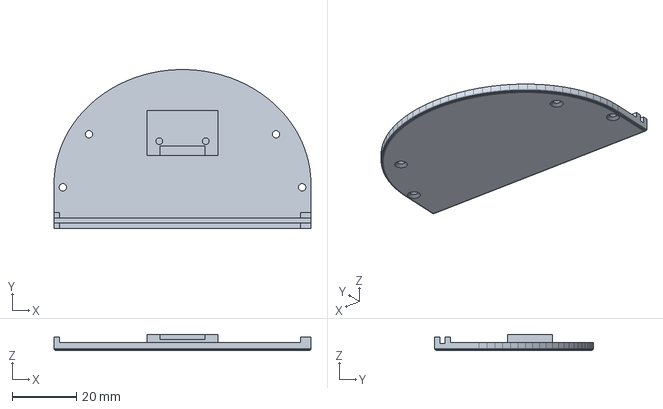
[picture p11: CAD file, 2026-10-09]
case/supermini_hud_plate_nofeet.step
79.7 x 49.3 x 5.00 mm

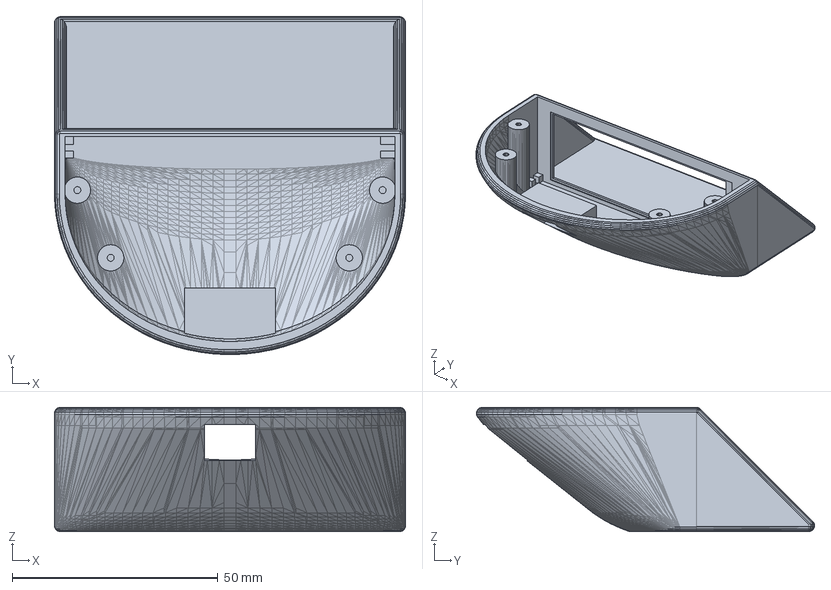
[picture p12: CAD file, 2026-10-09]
case/supermini_hud_shell.step
85.3 x 82.2 x 30.2 mm

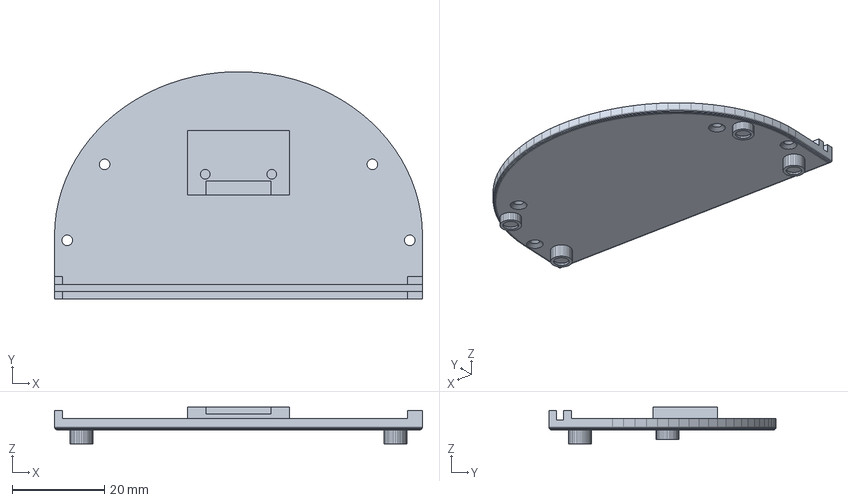
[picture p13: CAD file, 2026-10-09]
case/supermini_hud_plate.step
79.7 x 49.3 x 8.00 mm

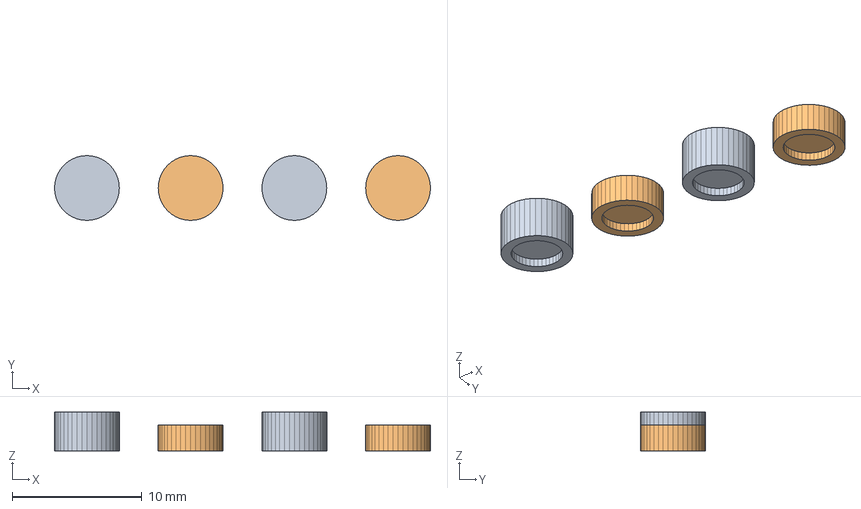
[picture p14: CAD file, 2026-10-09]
case/supermini_hud_feet.step
29.0 x 5.00 x 3.00 mm

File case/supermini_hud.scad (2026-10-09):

// =====================================================================
//  Small HUD enclosure — 2.79" TFT-SPI (GMT279-01M, 142x428, 78 x 25.9 mm PCB)
//  Two parts: top shell (window, 45° visor, rounded back) + bottom plate (screwed from below).
//  Material ASA. Units mm.
//
//  Axes: X = along the display (pin header / wires end = -X = left, holes end = +X = right),
//        Y = depth (0 = front face, +Y toward the windshield), Z = up.
//        Z = 0 is the top surface of the bottom plate; the plate is z = -plate_t .. 0.
//
//  PART = "shell" | "plate" | "plate_nofeet" | "feet" | "assembly"
// =====================================================================
PART = "assembly";

/* [Fit — ASA] */
clr_x   = 0.35;    // horizontal clearance per side (was 0.30, +0.05 after the first print)
clr_z   = 0.15;    // vertical clearance per side

/* [Display, from the drawing] */
pcb_l   = 78.0;  pcb_h = 25.9;  pcb_t = 1.2;
// distances from the pin-header end of the PCB (mm): [start, end]
bl_x    = [4.06, 73.49];   bl_h  = 24.38;   // backlight
tft_x   = [4.83, 72.72];   tft_h = 23.08;   // TFT glass (centred in the backlight)
aa_x    = [5.42, 69.56];   aa_h  = 21.28;   // active area, 64.14 long
stack_t = 2.0;             // BL + TFT thickness
tape_t  = 0.4;             // 3M between BL and PCB
pocket_d = 0.3;            // glass pocket depth in the front panel

/* [Window] */
m_left  = 0.30;            // margin around the active area, pin-header end (limited by the glass edge)
m_right = 1.00;            // holes end
m_z     = 0.40;            // top / bottom
bevel   = 1.0;             // 45° taper on the outside -> thin edge next to the glass (0.7 mm)

/* [Slots for the PCB ends] */
slot_right = 3.5;          // holes end: slot depth
corner     = 2.0;          // pin end: 2 x 2 mm corner pockets (bottom: plate, top: shell)
groove_d   = 0.3;          // groove under the PCB bottom edge in the plate
slot_clr   = 0.15;         // clearance on each side of the PCB thickness

/* [Shell] */
t_f       = 2.0;           // front panel
wall_top  = 2.0;
wall_side = 2.6;
plate_t   = 2.5;
round_r   = 1.5;           // outer edge radius (eco-leather friendly)
y_corner  = 20;            // virtual corner roof/slope: the roof is flat only just past the screen
fillet_r  = 30;            // smooth transition flat top -> slope
yc_bot    = 16;            // plan-view rounding starts here (floor level)
yc_top    = 5;             //   ... and here (top level)
cheek_t   = 3.0;  visor_t = 3.0;   // = 2*round_r: cheeks and visor are rounded on all edges

/* [Screws from below] */
j_pilot = 1.7;  j_hole = 2.3;  j_head = 3.9;

/* [Rear connector: mini-USB breakout, board trimmed] */
mu_w = 20.0;  mu_d = 13.0;  mu_hole_dx = 14.4;  mu_hole_to_face = 10.5;
mu_rec_w = 7.7;  mu_rec_h = 4.0;  mu_out = 1.0;  plug_over = 2.0;
mu_board_t = 1.6;  podium_h = 2.5;  mu_pilot = 2.1;

/* [Feet] */
foot_d = 5;  foot_front = 3;  foot_rear = 2;  pad_depth = 0.6;

$fn = 40;

// ---------------- derived ----------------
S       = 80.2;                       // distance between the pin-end stop wall and the holes-end slot floor
Hc_in   = S/2;                        // inner half width: the right slot floor is the inner side wall itself
W       = 2*(Hc_in + wall_side);
Xl      = -Hc_in;
XRf     = Xl + S;                     // right slot floor
pcb_x0  = Xl + clr_x;                 // PCB pin-end face (final position, pushed to the stop)
z_pb    = -groove_d;                  // PCB bottom edge
z_pt    = z_pb + pcb_h;               // PCB top edge
zc      = (z_pb + z_pt)/2;
ceil_in = z_pt + clr_z;
H       = ceil_in + wall_top;         // outer top
Zb      = -plate_t;                   // outer bottom
visor_len = H - Zb - 2*round_r;       // 45° cheeks
y_tft   = t_f - pocket_d;             // glass front
y_pf    = y_tft + stack_t + tape_t;   // PCB front face
y_pb    = y_pf + pcb_t;               // PCB back face
y_s1    = y_pf - slot_clr;            // slot front wall
y_s2    = y_pb + slot_clr;            // slot back wall
D       = W - visor_len;              // body depth at the floor -> total depth incl. visor = width
function dx(d) = pcb_x0 + d;

// ---------------- back shape (plan dome + side profile with fillet) ----------------
a_half  = W/2;
function cl(z) = max(0, min(H, z));
function yc(z) = yc_bot + (yc_top - yc_bot)*cl(z)/H;
th_deg  = atan((H-Zb)/(D-y_corner));              // straight slope from the corner down to the floor edge at y = D
y_k     = y_corner;
function prof_y(z, yk, Ht, R) = let(zt = Ht - R*(1-cos(th_deg)), yf = yk - R*tan(th_deg/2))
    z >= zt ? yf + sqrt(max(0, R*R - pow(z-(Ht-R),2))) : yk + (Ht - z)/tan(th_deg);
function yr(z)    = prof_y(cl(z), y_k, H, fillet_r);
function yr_in(z) = prof_y(cl(z), y_k - wall_top*tan(th_deg/2), H - wall_top, fillet_r - wall_top);
function outline(z, inner=false) = let(c=yc(z), a = inner ? a_half-wall_side : a_half,
                                       b = max((inner ? yr_in(z) : yr(z)) - c, 0.5))
    concat([[-a,0],[a,0]], [ for (t=[0:4:180]) [a*cos(t), c + b*sin(t)] ]);
function y_in_at(x, z) = let(c=yc(z), a=a_half-wall_side, b=yr_in(z)-c) c + b*sqrt(max(0,1-pow(x/a,2)));
module layers(off, za, zb, n=24, inner=false) {
    for (i=[0:n]) let(t=i/n, z = za + (zb-za)*(1-(1-t)*(1-t)))
        translate([0,0,z]) linear_extrude(0.01) offset(delta=off) polygon(outline(z, inner));
}
module core_outer() { hull() layers(0, Zb, H); }
module core_safe()  { hull() layers(-1.0, Zb+1, H-1, 14); }

// ---------------- mini-USB geometry ----------------
rec_z   = podium_h + mu_board_t + mu_rec_h/2;          // receptacle centre height
mu_y_in = yr(rec_z) - 8.5;                             // board edge / bulkhead start
mu_hy   = mu_y_in + mu_out - mu_hole_to_face;          // mounting holes line

// ---------------- screw pillars ----------------
function pil(sx) = [ [sx*(Hc_in-3.0), 15], [sx*29, y_in_at(29, 6) - 3.3] ];
pillars = [ for (sx=[-1,1]) each pil(sx) ];

// ---------------- shell ----------------
module body_solid() {
    r = round_r;  xo = W/2 - r;
    minkowski() { hull() layers(-r, Zb+r, H-r, 20); sphere(r=r, $fn=16); }
    // 45 deg cheeks (rounded plates) and the visor slab (rounded)
    for (sx=[-1,1]) hull() for (p=[[-visor_len+r, H-r],[r, H-r],[r, Zb+r]])
        translate([sx*xo, p[0], p[1]]) sphere(r=r-0.003, $fn=16);
    hull() for (sx=[-1,1], y=[-visor_len+r, r]) translate([sx*xo, y, H-r]) sphere(r=r-0.003, $fn=16);
}
module cavity() {
    intersection() {
        hull() layers(0, Zb-1, ceil_in, 26, true);
        translate([-Hc_in, t_f, Zb-2]) cube([2*Hc_in, 200, ceil_in-Zb+2]);
    }
}
module shell_cuts() {
    // glass pocket (inner side of the front panel)
    translate([dx(tft_x[0])-clr_x, y_tft, zc-tft_h/2-clr_z])
        cube([tft_x[1]-tft_x[0]+2*clr_x, pocket_d+0.02, tft_h+2*clr_z]);
    // window: narrow edge next to the glass, 45° taper opening to the outside
    wx0 = dx(aa_x[0]) - m_left;   wx1 = dx(aa_x[1]) + m_right;
    wz0 = zc - aa_h/2 - m_z;      wz1 = zc + aa_h/2 + m_z;
    hull() {
        translate([wx0-bevel, -0.02, wz0-bevel]) cube([wx1-wx0+2*bevel, 0.01, wz1-wz0+2*bevel]);
        translate([wx0, bevel, wz0]) cube([wx1-wx0, 0.01, wz1-wz0]);
    }
    translate([wx0, bevel-0.01, wz0]) cube([wx1-wx0, t_f, wz1-wz0]);
    // mini-USB tunnel (plug overmold is plug_over bigger than the receptacle on each side)
    ow = mu_rec_w/2 + plug_over + 0.4;  oh = mu_rec_h/2 + plug_over + 0.4;
    translate([-ow, mu_y_in-0.01, rec_z-oh]) cube([2*ow, 40, 2*oh]);
    // screw pilots from below
    for (p=pillars) translate([p[0], p[1], -0.01]) cylinder(d=j_pilot, h=9);
}
module shell_adds() {
    intersection() {
        core_safe();
        union() {
            // screw pillars, floor to ceiling
            for (p=pillars) translate([p[0], p[1], -0.01]) cylinder(d=6.4, h=ceil_in+0.02);
            // top corner ribs (pin end): straddle the PCB top edge, 2 mm deep
            for (ys=[[t_f-0.01, y_s1], [y_s2, y_s2+1.75]])
                translate([-Hc_in, ys[0], z_pt-corner]) cube([corner, ys[1]-ys[0], ceil_in-(z_pt-corner)+0.02]);
            // right (holes end): short top corner posts, 3.5 mm deep, 2 mm high (like on the left)
            for (ys=[[t_f-0.01, y_s1], [y_s2, y_s2+1.75]])
                translate([XRf-slot_right, ys[0], z_pt-corner]) cube([slot_right+0.6, ys[1]-ys[0], ceil_in-(z_pt-corner)+0.02]);
            // mini-USB bulkhead
            translate([-mu_w/2-1, mu_y_in, -0.01]) cube([mu_w+2, 30, 14]);
        }
    }
}
module shell() {
    difference() {
        union() {
            difference() { body_solid(); cavity(); }
            shell_adds();
        }
        shell_cuts();
    }
}
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

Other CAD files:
case/supermini_hud_feet.stl
case/supermini_hud_plate.stl
case/supermini_hud_plate_nofeet.stl
case/supermini_hud_shell.stl
case/supermini_hud_shell_var2.stl

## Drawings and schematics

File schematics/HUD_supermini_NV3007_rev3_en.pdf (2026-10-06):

# HUD — ESP32-S3 Super Mini + NV3007 2.79″

## Vehicle

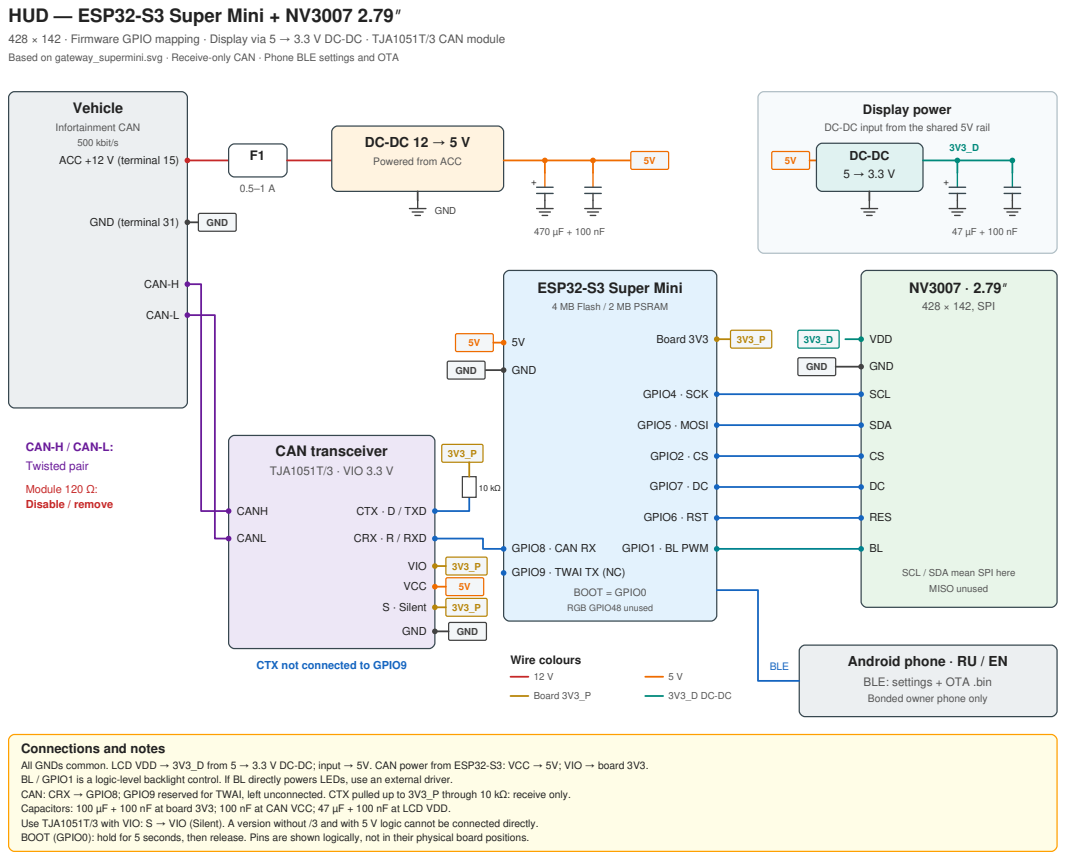
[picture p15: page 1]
Infortainment CAN; ACC +12 V (terminal 15); GND (terminal 31); GND; CAN-H; CAN-L; Board 3V3; BOOT = GPIO0 RGB GPIO48 unused; NV3007 · 2.79″ 428 × 142, SPI; VDD; GPIO4 · SCK; SCL; GPIO5 · MOSI; SDA; GPIO2 · CS; GPIO7 · DC; GPIO6 · RST; RES; GPIO1 · BL PWM; CAN transceiver TJA1051T/3 · VIO 3.3 V; CANH; CANL; CAN-H / CAN-L: Twisted pair; Module 120 Ω:; Disable / remove; CTX · D / TXD; CRX · R / RXD; VIO; VCC; S · Silent; CTX not connected to GPIO9; Android phone · RU / EN; Board 3V3_P; 500 kbit/s

428 × 142 · Firmware GPIO mapping · Display via 5 → 3.3 V DC-DC · TJA1051T/3 CAN module
Based on gateway_supermini.svg · Receive-only CAN · Phone BLE settings and OTA

Display power
DC-DC input from the shared 5V rail

Powered from ACC

ESP32-S3 Super Mini
4 MB Flash / 2 MB PSRAM

GPIO8 · CAN RX
GPIO9 · TWAI TX (NC)

SCL / SDA mean SPI here
MISO unused

BLE Wire colours

BLE: settings + OTA .bin
Bonded owner phone only

Connections and notes
All GNDs common. LCD VDD → 3V3_D from 5 → 3.3 V DC-DC; input → 5V. CAN power from ESP32-S3: VCC → 5V; VIO → board 3V3.
BL / GPIO1 is a logic-level backlight control. If BL directly powers LEDs, use an external driver.
CAN: CRX → GPIO8; GPIO9 reserved for TWAI, left unconnected. CTX pulled up to 3V3_P through 10 kΩ: receive only.
Capacitors: 100 µF + 100 nF at board 3V3; 100 nF at CAN VCC; 47 µF + 100 nF at LCD VDD.
Use TJA1051T/3 with VIO: S → VIO (Silent). A version without /3 and with 5 V logic cannot be connected directly.
BOOT (GPIO0): hold for 5 seconds, then release. Pins are shown logically, not in their physical board positions.

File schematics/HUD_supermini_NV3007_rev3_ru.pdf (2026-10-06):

# HUD — ESP32-S3 Super Mini + NV3007 2.79″

## Автомобиль

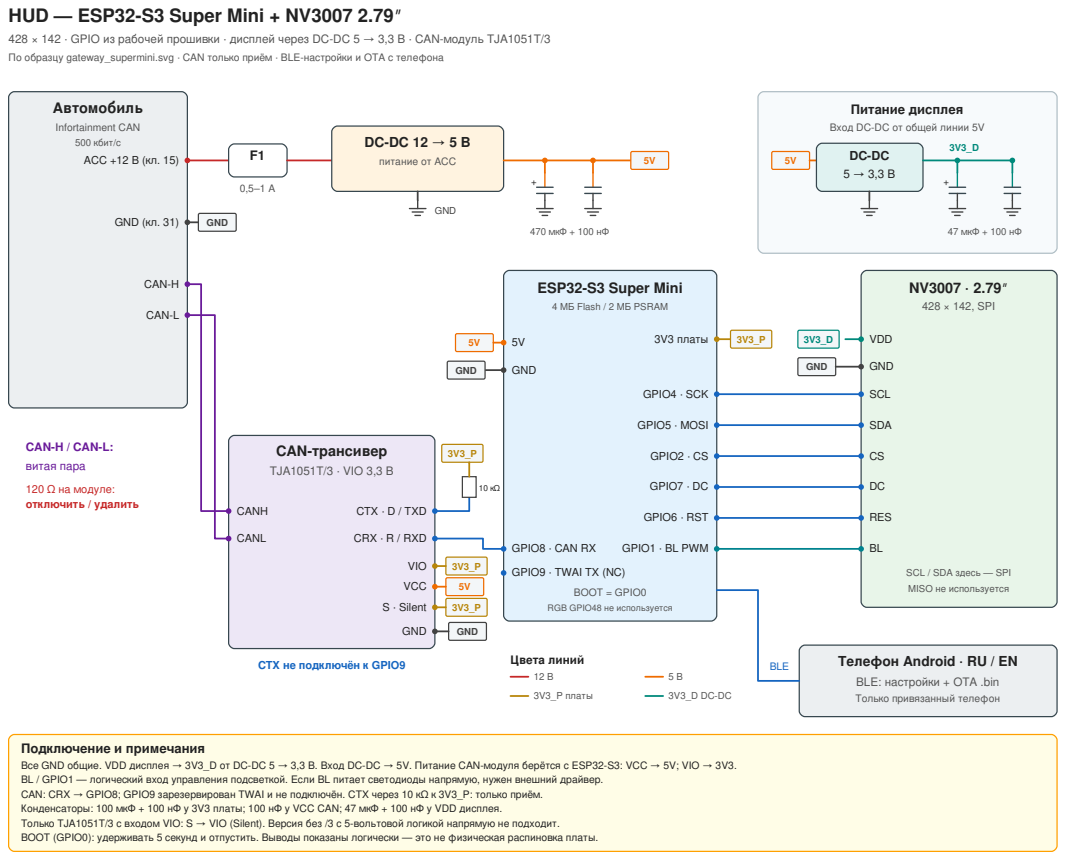
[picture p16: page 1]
Infortainment CAN; ACC +12 В (кл. 15); GND (кл. 31); GND; CAN-H; CAN-L; 470 мкФ + 100 нФ; 47 мкФ + 100 нФ; 3V3 платы; NV3007 · 2.79″ 428 × 142, SPI; VDD; GPIO4 · SCK; SCL; GPIO5 · MOSI; SDA; GPIO2 · CS; GPIO7 · DC; GPIO6 · RST; RES; GPIO1 · BL PWM; CAN-трансивер TJA1051T/3 · VIO 3,3 В; CANH; CANL; CAN-H / CAN-L: витая пара; 120 Ω на модуле:; отключить / удалить; CTX · D / TXD; CRX · R / RXD; VIO; VCC; S · Silent; CTX не подключён к GPIO9; Телефон Android · RU / EN; 3V3_P платы; 500 кбит/с

428 × 142 · GPIO из рабочей прошивки · дисплей через DC-DC 5 → 3,3 В · CAN-модуль TJA1051T/3
По образцу gateway_supermini.svg · CAN только приём · BLE-настройки и OTA с телефона

Питание дисплея
Вход DC-DC от общей линии 5V

питание от ACC

ESP32-S3 Super Mini
4 МБ Flash / 2 МБ PSRAM

GPIO8 · CAN RX
GPIO9 · TWAI TX (NC)

SCL / SDA здесь — SPI
MISO не используется

BOOT = GPIO0
RGB GPIO48 не используется

BLE Цвета линий

BLE: настройки + OTA .bin
Только привязанный телефон

Подключение и примечания
Все GND общие. VDD дисплея → 3V3_D от DC-DC 5 → 3,3 В. Вход DC-DC → 5V. Питание CAN-модуля берётся с ESP32-S3: VCC → 5V; VIO → 3V3.
BL / GPIO1 — логический вход управления подсветкой. Если BL питает светодиоды напрямую, нужен внешний драйвер.
CAN: CRX → GPIO8; GPIO9 зарезервирован TWAI и не подключён. CTX через 10 кΩ к 3V3_P: только приём.
Конденсаторы: 100 мкФ + 100 нФ у 3V3 платы; 100 нФ у VCC CAN; 47 мкФ + 100 нФ у VDD дисплея.
Только TJA1051T/3 с входом VIO: S → VIO (Silent). Версия без /3 с 5-вольтовой логикой напрямую не подходит.
BOOT (GPIO0): удерживать 5 секунд и отпустить. Выводы показаны логически — это не физическая распиновка платы.

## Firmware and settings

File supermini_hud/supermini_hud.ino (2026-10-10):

/* HUD v29.1.9 port: ESP32-S3 Super Mini 4 MB / 2 MB, NV3007 428x142. */
#include "user_config.h"
#include "lvgl_port.h"
#include "lvgl.h"
#include "hud_config.h"
#include "hud_source.h"
#include "hud_ble_settings.h"
#include "hud_log.h"
#include "src/lcd_bl_bsp/lcd_bl_pwm_bsp.h"

void lvgl_log_cb(const char *buf)
{
    if (HUD_LOG_LVGL) { hud_log_write("[LVGL] "); hud_log_write(buf); }
}

void setup()
{
    Serial.begin(115200);
    delay(300);
    Serial.println("[fw] HUD Super Mini v29.1.9 / BLE OTA");
    /* Legacy duty convention: 255 = dark, 0 = full brightness. */
    lcd_bl_pwm_bsp_init(255);
    hud_log_write("=== Super Mini / NV3007 HUD ===\n");
#if LV_USE_LOG
    lv_log_register_print_cb(lvgl_log_cb);
#endif
    hud_ble_settings_begin();
    lvgl_port_init();
    setUpduty(255 - HUD_BRIGHT_NO_DATA);
    hud_source_start();
}

void loop() { hud_ble_settings_poll(); vTaskDelay(pdMS_TO_TICKS(20)); }

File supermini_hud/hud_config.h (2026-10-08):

/*
  hud_config.h — настройки сборки HUD
*/
#ifndef HUD_CONFIG_H
#define HUD_CONFIG_H

/* Внутренняя версия прошивки: major.minor.fix. */
#define HUD_FW_VERSION_MAJOR  29
#define HUD_FW_VERSION_MINOR  1
#define HUD_FW_VERSION_FIX    3
#define HUD_FW_VERSION_STRING "29.1.3"

/* ---- Источник данных ----
   HUD_SRC_BLE  — сырые CAN-кадры от сниффера / BLE-гейта по BLE (протокол ACL)
   HUD_SRC_TWAI — свой трансивер TJA1051T/3 прямо на шине I-CAN,
                  встроенный контроллер TWAI в режиме LISTEN_ONLY
   HUD_SRC_FAKE — встроенный генератор кадров, для проверки без машины
   HUD_SRC_AUTO — работают оба: если по своему трансиверу (TWAI) идут кадры —
                  используется он, BLE отключается; нет кадров по CAN дольше
                  HUD_AUTO_CAN_HOLD_MS — используется BLE от сниффера / гейта
   Декодер и экран одни и те же, меняется только откуда приходят кадры. */
#define HUD_SRC_BLE          0
#define HUD_SRC_TWAI         1
#define HUD_SRC_FAKE         2
#define HUD_SRC_AUTO         3
#define HUD_DATA_SOURCE      HUD_SRC_AUTO
#define HUD_AUTO_CAN_HOLD_MS 1000   /* AUTO: столько без кадров по CAN — переходим на BLE */

/* BLE-защита: код доступа задаётся в secrets.h (шаблон secrets.example.h).
   Столько неудач сопряжения подряд — на экране подсказка «сопряжение не принято» */
#define HUD_BLE_PAIR_MSG_AFTER 3

/* ---- TWAI (для HUD_SRC_TWAI и HUD_SRC_AUTO) ----
   Super Mini: RX GPIO8, TX GPIO9 (не подключён).
   TJA1051T/3: CRX/RXD -> GPIO8, VCC -> 5V платы,
   VIO и S (Silent) -> 3V3 платы, CTX/TXD через 10 кОм -> VIO.
   TWAI работает в LISTEN_ONLY. GPIO9 оставить свободным. */
#define HUD_CAN_RX_PIN       8
#define HUD_CAN_TX_PIN       9
#define HUD_CAN_BITRATE_K    500    /* I-CAN MLB-Evo — 500 кбит/с */

/* совместимость со старым переключателем */
#ifdef HUD_FAKE_FRAMES
#if HUD_FAKE_FRAMES
#undef  HUD_DATA_SOURCE
#define HUD_DATA_SOURCE      HUD_SRC_FAKE
#endif
#endif

/* 1 = мигать строго по биту *_Kombi_Takt (фаза как на приборке).
   0 = бит такта используется только как признак "поворотник включён",
       мигаем своим таймером 500/500 мс (на случай рваного такта по BLE). */
#define HUD_BLINK_FROM_TAKT  1

/* Имя сниффера в эфире */
#define HUD_SNIFFER_NAME     "S3-CAN-Sniffer"

/* Lane Assist: LDW_02 0x397 (~80 мс). В ACL — интервал, а не onchange:
   при onchange стабильное состояние не присылается, и значок гас бы по таймауту. */
#define LKA_MIN_INTERVAL_MS  500

/* ---- Яркость подсветки дисплея (0..255): освещённость x колёсико ----
   Два входа, оба от машины:
     освещённость — датчик RLS_01: LS_Helligkeit_FW (до 6126 лк), выше — по
       RLS_Vorfeldhelligkeit_Boost (до ~30000 лк на прямом солнце);
     колёсико подсветки — BCM1_04.BCM1_Stellgroesse_Kl_58s (1..100).
   Четыре угла — подсветка при минимальной / максимальной освещённости и колёсике
   на минимуме / максимуме; между углами — плавно (по освещённости — логарифмически,
   как видит глаз; по колёсику — линейно). Ночная яркость NV3007: 2..40. */
#define HUD_BR_DARK_WHEEL_MIN     2      /* темно,  колёсико на минимуме  */
#define HUD_BR_DARK_WHEEL_MAX     40     /* темно,  колёсико на максимуме */
#define HUD_BR_BRIGHT_WHEEL_MIN   200    /* солнце, колёсико на минимуме  */
#define HUD_BR_BRIGHT_WHEEL_MAX   255    /* солнце, колёсико на максимуме */
#define HUD_LIGHT_LUX_DARK        0      /* «минимальная освещённость», лк  */
#define HUD_LIGHT_LUX_BRIGHT      30000  /* «максимальная» — прямое солнце, лк */
#define HUD_WHEEL_DEFAULT         100    /* колёсико, пока его положение не пришло, % */
#define HUD_BRIGHT_NO_DATA    170    /* пока нет данных о яркости (и без связи)       */
#define HUD_BRIGHT_STEP       4      /* плавность: шаг изменения за 50 мс             */

/* ---- Опциональный датчик света: фоторезистор на ADC1 GPIO10 ----
   Фоторезистор подключается к 3V3 и GPIO10, резистор 10 кОм — от GPIO10 к GND,
   конденсатор 100 нФ — GPIO10 к GND. Используется только без свежего RLS_01. */
#define HUD_LDR_PIN           10
#define HUD_LDR_ON            0
#define HUD_LDR_DARK_MV       150
#define HUD_LDR_BRIGHT_MV     2500
#define HUD_LDR_MIN_SPAN_MV   300

/* ---- Язык и единицы ----
   Настройки задаются здесь и применяются при каждой загрузке. */
#define HUD_LANG_RU    0
#define HUD_LANG_EN    1
#define HUD_UNITS_KM   0     /* км/ч, км, м                               */
#define HUD_UNITS_MI   1     /* mph, mi, ft (скорость ACC/лимитера тоже)  */

#define HUD_LANG       HUD_LANG_RU
#define HUD_UNITS      HUD_UNITS_KM
#define HUD_VOLUME_GAL 0     /* «сколько заправить»: 0 — литры, 1 — галлоны США */
#define HUD_TANK_L     54    /* начальный объём бака, л; 1..200, затем настройка BLE/NVS              */
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

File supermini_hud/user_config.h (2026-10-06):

#ifndef USER_CONFIG_H
#define USER_CONFIG_H

/* GPIO numbers, not connector pin numbers. Edit to match your wiring. */
#define HUD_LCD_SCK      4
#define HUD_LCD_MOSI     5
#define HUD_LCD_CS       2
#define HUD_LCD_DC       7
#define HUD_LCD_RST      6
#define EXAMPLE_PIN_NUM_BK_LIGHT 1
#define HUD_LCD_SPI_HZ   20000000
#define HUD_LCD_ROTATION 1   /* 1 or 3: landscape */
#define HUD_LCD_INVERT   0
#define HUD_BL_ACTIVE_HIGH 1 /* BL is a logic input; use an external driver if needed */
#define HUD_LCD_COL_OFFSET_1 12
#define HUD_LCD_COL_OFFSET_2 14

#define HUD_PANEL_W     428
#define HUD_PANEL_H     142
/* Compact layout, scaled uniformly to the whole 428x142 panel.
   Navigation width: 192 -> 128 before final scaling. */
#define HUD_CANVAS_W    518
#define HUD_CANVAS_H    172
#define HUD_VIEW_H      HUD_PANEL_H
#define HUD_VIEW_Y      0
#define HUD_STRIPE_H    8
#define EXAMPLE_LVGL_TICK_PERIOD_MS 5
#define EXAMPLE_LVGL_TASK_MIN_DELAY_MS 5
#define EXAMPLE_LVGL_TASK_MAX_DELAY_MS 50

/* Phone settings (separate from BLE_PASSKEY of the CAN gateway). */
#define HUD_SETTINGS_PIN 482731
#define HUD_SETTINGS_BLE_NAME "HUD-SuperMini"
#define HUD_SETTINGS_BOOT_PIN 0
#define HUD_SETTINGS_BOOT_HOLD_MS 5000
#define HUD_SETTINGS_PAIR_TIMEOUT_MS 60000

#endif

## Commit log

2026-10-06 Publish SuperMini NV3007 HUD v29.0 with BLE OTA, bilingual docs and wiring
    [partitions.csv]
2026-10-06 docs: add RU/EN schematics with Infortainment CAN label; reference pairing PIN config
2026-10-06 docs: describe localized revision 3 schematics
2026-10-06 feat: persist BLE tank capacity and acceleration bar settings (firmware 29.1)
2026-10-06 feat: persist overspeed tolerance and handle zero without division
    [hud_ble_settings.cpp, hud_config.h]
2026-10-08 Fix Lane Assist rendering and source indicator
    [hud_config.h, hud_data.h, supermini_hud.ino]
2026-10-08 Added light sensor
2026-10-09 Case added
    [supermini_hud.scad, supermini_hud_feet.step, supermini_hud_feet.stl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]
2026-10-09 Document ASA enclosure models and preview
2026-10-09 Add Russian enclosure documentation and preview
2026-10-10 Apply Audi-style navigation arrow plate
2026-10-10 Обновить ссылки README для v29.1.9 и Android 1.4.1
2026-10-10 Исправить номер v29.1.9 в README
2026-10-10 Исправить ссылку SHA для v29.1.9
2026-10-10 Top shell with long visor, variant 2
    [supermini_hud_shell_var2.step, supermini_hud_shell_var2.stl]
2026-10-24 v31.0.0: Waveshare-style navigation, road-fill progress, async SPI DMA, camera alerts, MQB platform
    - navigation arrows and roads from the Waveshare project; distance bar replaced by road fill
    - async queued SPI DMA display path (HUD_LCD_ASYNC_DMA)
    - speed-camera alerts from W25Q128 (cams.bin over BLE), sound alerts
    - HUD_PLATFORM switch: MLB-Evo (default) and early MQB support (Octavia A7 logs)
    - README: platform and signal tables for MLB-Evo and MQB
    Claude-Session: https://claude.ai/code/session_01XbC1F6pNtmcao3wMqEYqXB
2026-10-25 Schematics and docs: Infotainment CAN (MLB-Evo) / Comfort CAN (MQB)
    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
2026-10-25 Schematics and README: CAN wire colors for MLB-Evo and MQB
    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
2026-10-25 README: MLB-Evo screenshots from real A4 logs (navigation, ACC, Lane Assist, speed cameras)
    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
2026-10-25 Display: HUD_LCD_MIRROR_X option (horizontal mirror in flush_cb)
    Software mirror for HUDs that are read in a windshield reflection: strip rows are
    reversed in place and the column window is mirrored. Works in the async DMA and the
    legacy blocking path; default 0, no change for existing builds. No firmware version change.
    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
2026-11-01 Cameras: look-ahead 1.4 s, tolerances 22 m / 35 deg, hysteresis x1.5, hold last hit on gate flicker
    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
2026-11-01 Cameras: no hold after the camera display is switched off
    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
2026-11-03 v31.2.0: animated navigation arrows (arrows.bin), single low camera beep
    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
2026-11-03 gen_arrow_anim: straight-ahead animation smoothed from 13 to 36 frames
    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
